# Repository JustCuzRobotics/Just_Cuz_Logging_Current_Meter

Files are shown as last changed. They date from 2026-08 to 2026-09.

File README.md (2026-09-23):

# RC Logging Current Meter

A 150 A / 60 V inline power meter and datalogger for RC ESC test benches, a WM150-class
meter with live logging, a graphing touchscreen, and thermistor plus ESC-signal channels.

**Status: Rev A built, assembled and brought up (2026-08-25).** Display, capacitive touch,
all four analog channels, backlight and the ESC output all work. Voltage and thermistor are
calibrated. **Two known Rev A faults: the buttons are dead (footprint pad mapping) and
`JP1` ships open.** See "Known open items". Bring-up firmware is in `firmware/`.

Placement

---

## What it does

| Parameter | Value |
|---|---|
| Max voltage | 60 V DC (14S LiPo) |
| Max current | **150 A burst**, ~60 A continuous, limited by the XT60 rather than the sensor |
| Current sensor | ACS770KCB-150U, Hall, galvanically isolated, 100 µΩ conductor |
| MCU | Waveshare RP2040-Zero |
| Display | 3.5" 480×320 IPS, ST7796U + FT6336U touch + microSD, 14-way FPC |
| Logging | microSD **and** USB CDC CSV, up to 76 Hz (every sample tick) |
| Channels | current, pack voltage, 5 V rail, 1× 100 k NTC, plus ESC signal out |
| Board | 95 × 62 mm, 4 layer, 1 oz outer / 0.5 oz inner |
| Assembled PCB | ≈ $15/board delivered, at qty 10 (JLCPCB: bare board + SMT parts + assembly + shipping) |
| Complete unit | ≈ $44/board, adding the display, RP2040-Zero, connectors, NTC and hardware |

**Read the accuracy budget in [`DESIGN.md`](DESIGN.md) §5 before trusting a number.** Short
version: honest between roughly 30 A and 150 A, and increasingly meaningless below ~20 A,
because a ±1%-of-full-scale nonlinearity term is a fixed ±1.5 A regardless of reading. That
is inherent to putting a 150 A Hall sensor on a small current. For *comparative* testing,
same board, same session, ESC A vs ESC B, the systematic terms cancel and repeatability is
far better than the absolute figures.

## Two ideas worth sharing

**The ratiometric trick (§4.2).** The sensor's output scales with its own supply, which here
is raw USB VBUS, sagging with cable resistance and modulated by the display backlight PWM.
Rather than fight that with a regulator, a second divider measures the 5 V rail, and the
current is recovered from the *ratio*. Both V_CC and V_REF cancel algebraically, so accuracy
depends only on two resistor ratios and the sensor's own spec.

**The current path crosses the short dimension.** The ACS770's terminals sit side by side,
so rotating it 90° and stacking the connectors above and below gives a ~28 mm connector-to-
connector path. The ground return, not the sensor, turns out to dominate the loss budget.
See §8.

---

## Repository layout

```
Logging_Current_Meter.kicad_sch    schematic
Logging_Current_Meter.kicad_pcb    board, 95 × 62 mm, 4 layer
LCM.kicad_sym / LCM.pretty         all project symbols and footprints, self-contained
production/                        gerbers, BOM, positions and IPC netlist as sent to fab
DESIGN.md                          the real documentation, reasoning, maths, decisions
BOM.md / BOM.csv                   bill of materials, generated from the schematic
generator/                         the Python that builds and checks all of the above
firmware/                          bring-up diagnostic and the touchscreen UI, one folder per sketch
tools/capture_stream.py            records the meter's USB CSV stream on a PC
tools/log_analyzer.py              GUI: graphs, summary CSV and run comparisons from SD logs
libraries/JCR_TouchScreen/         reusable ST7796 + FT6336U display and touch library
COMMIT_TIMELINE.md                 full detail behind every commit, newest first
```

`DESIGN.md` is the substantive document; this README is only an index. It records *why*
each choice was made, including the ones that turned out wrong and were reversed.

---

## The generator / verifier toolchain

The schematic and board are hand-edited in KiCad, but every mechanical change is applied by
script and checked by an independent verifier. The rule throughout: **the checker re-reads
the finished file from disk and re-derives everything, so it can disagree with the tool that
wrote it.**

**Requires KiCad 10 or newer.** The schematic and board are now in KiCad 10 format
(`20260306` and `20260206`), written by KiCad itself. KiCad refuses to open files stamped
newer than the running version, so an older install will not open this project at all.

```bash
cd generator

# check, read-only, safe at any time
python3 verify.py     ../Logging_Current_Meter.kicad_sch ../LCM.kicad_sym
python3 verify_pcb.py ../Logging_Current_Meter.kicad_pcb ../Logging_Current_Meter.kicad_sch

# regenerate derived artefacts
python3 gen_bom.py                                    # BOM.md + BOM.csv from the schematic
python3 copper_budget.py ../Logging_Current_Meter.kicad_pcb   # 150 A loss budget
python3 region_map.py    ../Logging_Current_Meter.kicad_pcb   # the §14 layout map
python3 render_pcb.py    ../Logging_Current_Meter.kicad_pcb ../placement.svg
```

> **`gen_sch.py` is a historical build script, not a live tool.** `generator/kicad8.py`
> hardcodes `SCH_VERSION = 20231120`, so re-running it would overwrite the KiCad 10
> schematic with a KiCad 8 one and discard every edit made in KiCad since. `gen_pcb.py`
> was updated for KiCad 10; `gen_sch.py` was not.

`verify.py` rebuilds the netlist **geometrically**, so pins, wire endpoints and label anchors
sharing a coordinate are one node, then compares it against an independently written
expectation of all nets and pin connections. `verify_pcb.py` runs nine checks over the
board: s-expression syntax, footprint inventory against the schematic, net coverage, board
extent, courtyard overlaps, stale net names, pour and stitching integrity, components inside
soldermask openings, and pad-to-pad clearance against the resolved netclass rules.

Both currently pass clean.

> **`gen_pcb.py` will refuse to run its `place` or `pour` stages once the board has routed
> tracks**, because both would destroy hand routing. Override with `--force` only after
> re-syncing the placement table from the board.

Every check in `verify_pcb.py` exists because something actually went wrong: a quoted
s-expression tag that made KiCad reject the file, a net rename that left a dead name on a
live pad, a resistor placed inside a soldermask aperture, a netclass clearance that made a
0.5 mm-pitch connector unroutable. The commentary in the source explains each one.

---

## Known open items

### Rev A hardware faults

- **`JP1` ships open — bridge it or the display is dead.** It is the display's only supply.
  Bridge pad 2 (`DISP_VCC`) to pad 1 (`+5V`). No backlight, no SPI and no I²C until you do,
  which makes it look like a much bigger problem than it is. `DESIGN.md` §9.
- **`J7` needs a TYPE A (same-side) FFC cable.** The one in the display's box is Type B and
  reverses the pin order, putting 5 V on the module's `SD_CS` while `VCC` sits unpowered.
  14 pin, 0.5 mm pitch, Type A, ≤100 mm. `DESIGN.md` §9.
- **SW1/SW2 are dead — footprint pad mapping is wrong.** `SW_TS-1187A` was remapped
  assuming internal pairs 1–3/2–4; they are 1–2/3–4, so both buttons short `BTN1` to `GND`
  permanently. Rev B fix, plus a lift-two-legs bodge for Rev A. Calibration runs from
  serial commands instead. `DESIGN.md` §9.
- **RV1 footprint.** Corrected in the library to the real 3362P triangle but **not yet
  applied to the board**. *Update Footprints from Library* moves all three pads 1.27 mm and
  needs `T_NODE` and `T_POT_TOP` re-routed. `DESIGN.md` §4.4.
- **D1 / U1 courtyards overlap by 3.49 × 0.45 mm.** Courtyard margin only — no pad, body or
  silk inside it. KiCad will keep flagging it. Not a bug.

### Firmware

- **Bring-up diagnostic is complete** and lives in `firmware/display_bringup/`. It exercises
  all 20 GPIO, reports pass/fail per subsystem with net names, and runs the calibration
  routines.
- **Current gain is the last uncalibrated channel.** Voltage, thermistor and the current
  zero are done and baked in.
- **The touchscreen UI is built and running**, in `firmware/logging_current_meter_FABLE/`
  (v3.6): live V/I/T/W, energy accumulation, an autoscaled 5 s graph, **Test Mode** (ESC
  signal on GP1 for uni- or bidirectional ESCs — manual buttons or slider with a dead-man
  option, ramped auto-cycle, and a counted **Log Test** that records itself), **SD logging**
  (manual, Test-cycle or current-threshold start, 1–15 min duration) with a **USB CSV
  stream**, a Settings screen
  with flash persistence and a settable wall clock that stamps every log with the date and
  time it was recorded, dark and navy themes, a tunable weighted filter on the V and I
  readings, and a touch diagnostic screen with a serial telemetry harness. Its display and
  touch stack is factored out into `libraries/JCR_TouchScreen/`. Architecture and the
  measured sampling constraints are in `DESIGN.md` §11.
- **Touch responsiveness fading with use is under investigation.** v3.1b's register
  watchdog found the FT6336U's mode register losing its value on its own (47 times in
  39 minutes) and now rewrites it within 500 ms; the per-register breakdown in v3.1c will
  say whether the part is resetting or one register is flaky.
- **v3.2a is bench-verified** (ESC timing, SD logging, USB stream, log analyzer).
  **v3.3** (the Test Mode rework), **v3.4** (the wall clock), **v3.5** (ESC arming, pre-roll
  and stop escalation) and **v3.6** (cycle mode: STOP→SPIN / SPIN→SPIN in place of the old
  mirrored DIRECTION) are compile-checked and host-tested; each bench run has fed the next,
  and v3.6 is not yet on the bench.
- ~~**microSD MISO tri-state risk.**~~ Inconclusive so far, and **not a blocker** — the
  panel is driven write-only and works. With no card in the slot nothing drives MISO on
  these modules, so `0xFF` is the expected reading. The §11 question only has meaning with
  a card inserted.

## Sourcing note

Three cost figures get confused, so to be explicit. `BOM.md`'s **$10.75** is the theoretical
SMT parts cost at LCSC unit prices, and it is the only one the generator computes. The
**$15** above is what a delivered assembled board actually cost at qty 10, and the real
PCBA line came in at $11.06/board against that $10.75 estimate, which is close enough to
validate the generated BOM. **$44** is a complete working meter, and the display alone is
$18.99 of it. All three are at qty 10; setup and shipping amortise, so a one-off build costs
considerably more per board.

The ACS770 is marked *not for new designs* but remains in stock. **ACS772KCB-150U-PFF-T is
a drop-in replacement requiring no board changes at all**, same package, same 26.66 mV/A,
same quiescent output, same ratiometric behaviour, same load limits. `DESIGN.md` §4.1.1 has
the full comparison, including which of the commonly-quoted differences are wrong.

## Licence

- **Hardware** (schematic, PCB, footprints, symbols, BOM, documentation):
  [CC BY-NC-SA 4.0](LICENSE), plus the additional permissions below.
- **Software** (the Python in `generator/`):
  [PolyForm Noncommercial 1.0.0](generator/LICENSE), plus the same additional permissions.

### What you can do

Build one. Build several. Modify the design. Use it at work, in a business, in a makerspace,
in a classroom, or in a paid repair shop. Put it in a monetised YouTube video, a paid course,
or a magazine article. Publish your modified version, as long as you credit this project and
licence your version the same way.

### What you cannot do

Sell the design files. Sell hardware built from them, whether assembled boards, bare PCBs, or
kits. Bundle either into a product you sell. Selling kits is how this project funds itself,
so that part is reserved.

Want to sell something based on this? Ask. Contact **team@justcuzrobotics.com**.

### Why it is written this way

CC BY-NC-SA's "NonCommercial" clause is broader than the intent above; read strictly it would
also block using one at work or in a monetised video. The additional permissions in the
LICENSE files grant those uses explicitly, so the only real restriction is on selling the
design or hardware.

Because commercial sale is restricted, this is source-available rather than open source in
the OSI or OSHWA sense.

Copyright © 2026 Seth Schaffer / Just 'Cuz Robotics

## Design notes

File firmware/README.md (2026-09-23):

# Firmware

| Sketch | Purpose |
|---|---|
| `display_bringup/` | Full board diagnostic and calibration tool. Exercises all 20 usable GPIO, reports pass/fail per subsystem with net names, and fits the analog calibration constants |
| `logging_current_meter_FABLE/` | **The current UI (v3.6).** Live V/I/T/W, energy and run timer, autoscaled 5 s graph, Test Mode (manual / ramped cycle / logged cycle test, one-direction or bidirectional ESCs), **SD logging with manual / cycle / current-threshold start and a USB CSV stream**, Settings with flash persistence, a settable wall clock that stamps logs, two themes, tunable V/I filter, touch diagnostics with a serial telemetry harness. One module per concern; built on `libraries/JCR_TouchScreen/` |
| `FABLE_DEV_TEST_SCREEN/` | Minimal touch-reliability test firmware. The quickest way to prove a panel and its touch mapping in isolation |
| `logging_current_meter_ui/` | Superseded predecessor (v1.7, Arduino_GFX). Kept as a reference until the new UI is bench-verified |
| `touch_dev_test/` | Earlier touch experiment. Superseded; not a reference |
| `_archive/` | Point-in-time copies of superseded firmware, kept as rollbacks. Not compiled — the extensions are deliberately not `.ino` |

**Datalogging to microSD and the USB stream are built as of v3.2** (compile-checked and
simulated on the host; not yet bench-verified). See *Logging* under
`logging_current_meter_FABLE` below. `tools/capture_stream.py` records the stream on a PC.

---

## `display_bringup`

**Everything reports over USB serial at 115200.** The display is treated as one more
subsystem under test — if the panel is dead, every other test still runs and still reports.
Do not rely on the screen to tell you anything.

> **USB power only.** Nothing in the 60 V current path, except during a deliberate voltage
> calibration. The sketch checks `V_PACK` at boot and shouts if it sees pack voltage.

### Toolchain

- **Board:** Arduino IDE → *"Raspberry Pi Pico/RP2040"* by **Earle Philhower**, board
  **Waveshare RP2040 Zero**
- **Library:** **"GFX Library for Arduino"** by *moononournation*. **Not Adafruit_GFX** —
  different library, different header, no ST7796 driver. Required by `display_bringup`
  and by the superseded `logging_current_meter_ui` only
- **Touch:** no library; the FT6336U is driven register-direct
- **Serial Monitor:** 115200, and **set the line ending to Newline** or no command you type
  will ever register

### Commands

| | |
|---|---|
| `a` / `A` | analog report, with expected values / streaming at 2 Hz |
| `b` | button report — idle level, press count, hold time, measured bounce |
| `c` | show the stored calibration constants |
| `s` | GPIO bridge / short test (unplug the ribbon first) |
| `k` | backlight ramp |
| `m` | MISO read-back, the `DESIGN.md` §11 test |
| `d` | display test pattern |
| `t` / `x` | touch controller scan and identity / coordinate stream |
| `g` | **live V/I graph — 5 s scrolling window, volts blue, amps red** |
| `e` / `l` | ESC signal output on GP1 / GP0↔ESC_SIG loopback |
| `n` / `v` / `i` | thermistor / voltage / current calibration |
| `r` / `?` | re-run the full sequence / help |

Streams stop on any key — an actual character, not a bare Enter.

### Calibration

Constants are **baked into the top of the sketch** and applied from boot, so they survive a
reflash. Each routine prints `#define` lines to paste back in. Press `c` to see what is
stored and which channels are genuinely calibrated.

Current state: voltage **fitted**, thermistor **fitted**, current **zero fitted / gain
nominal**. Full procedure and the reasoning behind each choice is in `DESIGN.md` §6.

Three things that will waste your time if you skip them:

- **Voltage needs two points with an offset**, not one through the origin. There is a real
  8.2 ADC count zero offset; ignoring it costs over 1 % at low pack voltages.
- **Fit the current gain at the highest current you can source.** The ±1.5 A nonlinearity
  floor is ±5 % of a 30 A fit but ±37 % of a 4 A one.
- **Do not use an ice bath for the thermistor.** Wet leads shunt it by ~340 kΩ — a 49 %
  error at 0 °C and 2 % at 100 °C. Room temperature plus boiling gives 77 °C of spread and
  works properly.

### Before first power-up on a new board

Board unpowered, DMM in continuity mode. All three of these cost an evening each the first
time. `DESIGN.md` §9 has the detail.

1. **Bridge `JP1`** — pad 2 (`DISP_VCC`) to pad 1 (`+5V`). It ships open and it is the
   display's only supply. Confirm pad 2 is *not* also bridged to pad 3.
2. **Use a Type A (same-side) FFC cable** for `J7`. The one in the display's box is Type B
   and reverses the pin order.
3. **Check `R11`–`R14` are fitted.** All four are 0 Ω placeholders in the SPI and backlight
   paths; a missing one is an open circuit, not a default.

### Known Rev A fault

**SW1 and SW2 are permanently shorted to GND** — the `SW_TS-1187A` footprint pad remap
assumed the wrong internal pairing. Everything is therefore driven by serial commands. Any
firmware built on this must not assume the buttons exist. `DESIGN.md` §9.

### Pin map

Mirrors `EXPECTED_MCU` in `generator/verify.py`. Verified against both that and the
module's own pin table.

| FPC | Module | Net | RP2040 |
|---|---|---|---|
| 1 | VCC | `DISP_VCC` | via `JP1` |
| 2 | GND | `GND` | — |
| 3 | LCD_CS | `LCD_CS` | GP5 |
| 4 | LCD_RST | `LCD_RST` | GP7 |
| 5 | LCD_RS | `LCD_RS` | GP6 |
| 6 | SDI (MOSI) | `SPI_MOSI` | GP3 via `R12` |
| 7 | SCK | `SPI_SCK` | GP2 via `R11` |
| 8 | LED | `DISP_LED` | GP8 via `R14` |
| 9 | SDO (MISO) | `SPI_MISO` | GP4 via `R13` |
| 10 | CTP_SCL | `CTP_SCL` | GP11 |
| 11 | CTP_RST | `CTP_RST` | GP12 |
| 12 | CTP_SDA | `CTP_SDA` | GP10 |
| 13 | CTP_INT | `CTP_INT` | GP13 |
| 14 | SD_CS | `SD_CS` | GP9 |

Analog: GP26 `I_SENSE`, GP27 `V_PACK`, GP28 `T_SENSE`, GP29 `V5_SENSE`.
Other: GP0 spare (J13 pad), GP1 `ESC_SIG_MCU`, GP14/GP15 buttons.

---

## `logging_current_meter_FABLE`

The working UI. **Uses no third-party graphics library** — the display, touch and text
stack lives in `libraries/JCR_TouchScreen/`, which must be on the Arduino library path
before this sketch will build:

```
arduino-cli compile --fqbn rp2040:rp2040:waveshare_rp2040_zero firmware/logging_current_meter_FABLE
```

Rather than copying the library into the sketchbook and forgetting to re-copy it, make the
sketchbook entry a junction to the repo copy — then every library edit is what the IDE
compiles:

```powershell
New-Item -ItemType Junction -Path "$HOME\Documents\Arduino\libraries\JCR_TouchScreen" `
         -Target "<repo>\libraries\JCR_TouchScreen"
```

**The panel is IPS and needs display inversion on.** `Config.h` sets `LCD_IPS 1`, which the
library turns into `INVON`. Without it every colour displays as its complement — black is
white — which is exactly how v2.0 through v3.1a looked, and why the themes made no sense
until v3.1b.

### Why touch is arranged the way it is

These panels are notorious for dropped taps, and the cause is not the hardware. The
FT6336U ships in trigger mode, where `CTP_INT` only pulses on state *changes*, so a short
tap can be missed outright; and reading touch from the drawing loop means any slow frame
stretches the gap between reads until brief contacts land and lift unseen. A third trap:
monitor mode is enabled by default and quietly drops the scan rate after ~30 s idle, which
reads as "touch goes dead if you leave it alone".

So the arrangement is inverted. **Core 1 owns touch and the ADC; core 0 owns the display.**
The controller runs in polling mode and is sampled at a fixed 200 Hz, interleaved *between*
the four ADC channel bursts so a ~5 ms acquisition can never delay a touch sample by more
than one channel. Press and release become queued events, so a slow frame delays the
*reaction* to a tap, never its *registration*.

Four rules keep that true as features are added. They are restated in the sketch header:

1. Core 1 never blocks, prints or draws — sampling and touch servicing only.
2. Core 0 may be arbitrarily slow; drain touch events every pass regardless.
3. Never repaint the whole screen per tick. Chrome once on entry, then only the fields
   that changed. A full-screen fill is ~60 ms even at 40 MHz.
4. Core 0 never touches the ADC; core 1 never touches SPI.

### Layout

One file per concern. `Config.h` holds the pin map, bus rates and **the calibration
constants** — that is the file to edit after running `display_bringup`'s `v`/`i`/`n`
routines (Settings → DUMP prints the current ones over serial). `Layout.h` holds every
pixel coordinate and touch target, so retargeting to another panel size is one file.
`Sampler.*` is the core-1 ADC, the V/I weighted-moving-average filter and the graph ring;
`Settings.*` the user settings and their EEPROM persistence (explicit Save only — a flash
write halts both cores for a few ms); `Clock.*` the wall clock and its date maths
(unit-tested on the host), `ScreenClock.cpp` the SET CLOCK screen; `EscOut.*` the ESC output and motion engine on GP1 (the
core's Servo library — PIO, `writeMicroseconds()`, fixed 50 Hz — OFF at boot, always arms at
idle with a 2 s hold; manual, ramped cycle and Log Test phases), `EscProfile.h` the pure
profile maths (unit-tested on the host), `ScreenTest*.cpp` the three Test Mode tabs; `Logger.*` the SD
log, its triggers and the USB stream; `Version.h` the version string the banner and log
headers share; `Theme.*` the
two palettes behind the `COL_*` macros; `Widgets.*` the button chrome and cached fields;
`Screens.*` navigation, with one `Screen*.cpp` per screen.

### Serial keys (115200)

| key | does |
|---|---|
| `d` | once-per-second `[tp]` telemetry line: touch rate, UI rate, worst frame, tap latency, every touch counter, controller register drift per register, core-1 tick health |
| `r` | reset the touch counters |
| `t` | re-initialise the touch controller from core 1 |
| `L` | synthetic ~60 ms core-0 load per loop |
| `f` | filter 0 ↔ 20 samples |
| `e` | ESC output arm (idle 1000 µs, 2 s hold) / cut, then prints the ESC state |
| `p` | print the ESC state — attached, set point, pulse on the pin, hold/cycle |
| `s` | USB CSV stream on/off (not saved — the LOG screen's SAVE persists it) |
| `g` | SD log start / stop |
| `m` | remount the SD card (runs the read-back test) |
| `c` | the wall clock. `c` alone prints it; `c 1790084323` sets it from epoch seconds; `c 2026-09-23 14:05:30` sets it from a typed date. This is the only key that takes an argument, so it reads to the end of the line (or a 2 s gap between characters) |

**Every serial line that is not a CSV data row starts with `#`** as of v3.2, so a capture
can separate data from the banner, `[tp]` telemetry and `[log]` events by the first
character.

The `[tp]` line is the touch-investigation tool: `TP` dropping means core 1 is starved,
`lat` climbing with `TP` steady means core 0 is slow, `dn` not counting on a real tap means
the controller stopped reporting, and `drift=[a/b/c/d]` counts the controller's four
configuration registers found not holding their values (rewritten automatically).

### ESC output — the v3.1 timing bug

v3.1 drove GP1 with `analogWriteFreq(1e6/period)` + `analogWriteRange(period)`. **arduino-pico
clamps `analogWriteFreq()` to ≥ 100 Hz, silently**, so the 50 Hz frame ran at 100 Hz on a
20000-count range and every pulse was half width: "1000 µs idle" was 500 µs, "2000 µs"
was 1000 µs (any frame longer than 10 ms was scaled by 10000/period). Some ESCs reject a
500 µs pulse and never arm; others accept it as zero throttle. v3.2 uses arduino-pico's
bundled **Servo** library instead (PIO state machine, `writeMicroseconds()`), which is what
this should have used from the start. Its frame is fixed at 20 ms (50 Hz, a compile-time
constant in the library), so Test Mode's frame-period stepper is gone. It is attached as
`attach(pin, 1000, 2000, 1000)`: plain `attach(pin)` starts at 1500 µs. Check the waveform
on a scope before trusting a test — expect a 20 ms frame and a 1000 µs pulse after arming.

Arming now always emits 1000 µs for 2 s before the set point or a cycle applies, and the
set point resets to idle on arm. ESCs refuse to arm when their first frames carry
throttle.

### Test Mode (v3.3, arming reworked in v3.5)

Three tabs under one header: **MANUAL | CYCLE | LOG TEST**, with the arm/stop button at top
right. Leaving Test Mode does not stop a running cycle — the amber strip says the output is
live.

**The arm/stop button escalates** (v3.5), because "stop the motor" and "make the pin dead"
are different needs and an ESC charges several seconds of start-up for the second one:

| face | tap does | when |
|---|---|---|
| **ARM** | signal up at idle, 2 s hold | output off |
| **STOP** | idle now, signal still up — the motor stops, the ESC stays armed | something is moving |
| **CUT** | output off (at most one more idle pulse, within a 20 ms frame) | already at idle, nothing running |

Holding the button for a second cuts from a press that started on STOP. A press that started
on ARM never repeats, and sliding a finger off the button cancels the hold.

Whenever the output sits live at idle with nothing running, a fuse cuts it on its own: 30 s
after a run ended by itself, 5 minutes after a stop you asked for. Touching the throttle or
starting anything cancels it, and the MANUAL status line counts the 30 s one down.

**Pre-roll** (v3.5): every run — cycle or Log Test — starts with the output at idle for
**ESC PRE-ROLL** (Settings, 0–15 s, default 5 s) before the first ramp, with the 2 s arming
hold inside it. An ESC ignores throttle until it has finished its start-up beeps, so without
this the first ramp is half eaten and the motor jerks. Set it longer for an ESC with start-up
music. START also works with the output already live: it commands idle and pre-rolls, rather
than making you stop first.

- **ESC type** (MANUAL tab, locked while armed; an arrow icon, one head or two):
  **ONE DIRECTION** arms and idles at 1000 µs; **BIDIRECTIONAL** arms at 1500 µs neutral,
  with reverse below. Every arm holds idle for 2 s first. (Logs and serial still write the
  short tokens `esc=UNI` / `esc=BIDI`.)
- **Small/big step pairs:** wherever a row has a fine and a coarse button (MANUAL ±10/±50,
  the CYCLE editor), the coarse one is drawn in lime with a double ring.
- **MANUAL:** BUTTONS (−50 −10 +10 +50) or SLIDER (tap anywhere to jump, drag to adjust;
  BIDI centres on 1500 with a small detent). RELEASE: **HOLD** keeps the value when you lift;
  **DEAD-MAN** drops to idle on lift — and also if the UP event is lost or touch samples stop
  for 60 ms. Switching into slider + dead-man drops the set point to idle. IDLE returns to
  idle/neutral while staying armed.
- **CYCLE / LOG TEST** share one saved profile, edited by tapping a tile and using the
  editor row (hold 1 s to repeat at 5/s):

| Tile | Range | Steps |
|---|---|---|
| LOW US (SPIN→SPIN only; in STOP→SPIN it is the type's stop pulse, greyed) | 1000 – 2000 | 10 / 50 |
| SPIN US / HIGH US | 1000 – 2000 | 10 / 50 |
| RAMP UP / RAMP DOWN ms | 0 – 3000 (0 = instant step) | 50 / 500 |
| DWELL HI / DWELL LO ms | 500 – 180000 (3 min) | 50 / 500 below 5 s, **1 s / 10 s above** |
| CYCLE MODE | STOP→SPIN · SPIN→SPIN | ◀ ▶ |
| CYCLES (LOG TEST only) | 1 – 999 | 1 / 10 |

  **CYCLE MODE** (v3.6) decides what the bottom of a cycle is. **STOP→SPIN** locks the low end
  to the ESC type's stop pulse (1000 one-direction, 1500 bidirectional) and leaves SPIN US free
  across the whole 1000–2000 band — so a bidirectional ESC runs *backwards* simply by setting
  SPIN below 1500. The number on the screen is the number on the pin: no mirroring, and no
  direction setting (the v3.3–v3.5 DIRECTION tile is gone). **SPIN→SPIN** frees both ends, for
  cycling between two running points — two throttle levels, or one side of neutral to the other.
  Either order is allowed, so a profile can ramp downward. Note that a pulse below 1500 only
  means reverse if the ESC's own firmware is in bidirectional (3D) mode; otherwise it is just a
  low forward throttle. In SPIN→SPIN the run eases from the pre-roll's idle into LOW over the
  ramp-up time (a LEAD-IN phase) rather than stepping; STOP→SPIN skips it, since its low end is
  idle already. Changing ESC TYPE resets the cycle's low end to the new type's stop pulse and
  the mode to STOP→SPIN, because 1000 µs means "stopped" under one type and "full reverse"
  under the other.

  Millisecond tiles change gear with their own value: a 3-minute dwell set 500 ms at a time
  would be 360 taps, so above 5 s the buttons become 1 s and 10 s and relabel themselves
  (`+1 S`, `+10 S`) as you cross the threshold. Dwells are stored as 32-bit values for this.

  Defaults (RESET DEFAULTS, tap twice within 2 s): STOP→SPIN, spin 1500 µs (1750 for a
  bidirectional ESC), ramps 1000 ms, dwells 3000 ms, 10 cycles. The profile is locked while a run is
  active and snapshotted at its start.
- **CYCLE** runs RAMP UP → DWELL HI → RAMP DOWN → DWELL LO until STOP CYCLE (which leaves
  the output armed at idle). LOG MODE = CYCLE still auto-logs these runs.
- **LOG TEST**: opens `LOG_<n>_TEST_<V>V.CSV`, the pre-roll at idle (arming hold inside it),
  N cycles, 5 s post-roll, closes the log (`reason=complete`) and stays live at idle with the
  30 s fuse running. Starting it with the output already live is fine — it goes to neutral
  first, which also means the card mount can never block with a motor under throttle. ABORT TEST jumps to the post-roll at idle; header STOP
  cuts the output and finishes the post-roll unpowered — either way the spin-down is logged
  and the file ends `reason=aborted`. The header carries a `# profile …` line (ESC type,
  pulses, ramps, dwells, cycles, cycle mode) that the log analyzer shows in its stats box,
  and the main chart gains an ESC-pulse strip. While a test runs, the LOG screen's
  START/STOP and serial `g` are refused, the DURATION limit does not apply, and the CURRENT
  trigger stays out of the way.

### Settings

Six rows: **THEME**, **FILTER**, **CLOCK** (below), **ESC PRE-ROLL** (0–15 s in 0.5 s steps,
hold to repeat), **SETTINGS** (SAVE — the only thing that writes flash, because a commit
halts both cores), and **TOOLS** (calibration DUMP over serial, and DEV MODE). Everything
takes effect in RAM immediately; SAVE is what survives a power cycle.

### The wall clock (v3.4)

There is no RTC chip and no backup cell, so the clock is an epoch base plus `millis()`. It
exists to stamp logs with the day and time they were recorded; it is not a timebase for
anything measured (that is still the 13.158 ms tick). Local time only — no timezone, no DST.

- **Setting it:** Settings → CLOCK → **SET CLOCK** (YEAR / MONTH / DAY / HOUR / MIN tiles and
  the same editor row as the cycle profile, hold to repeat; APPLY sets the seconds to 00), or
  the serial `c` command, which is accurate to the second. `tools\capture_stream.py` sends
  `c <epoch>` on connect, so plugging in the laptop syncs the meter (`--no-set-clock` to skip).
- **Across power cycles:** the time is copied into the settings blob at log start and stop,
  on an explicit SAVE, when the clock is set, and every 5 minutes while idle. On boot the
  clock resumes from that copy, so it comes back with the right date and the time of the last
  save — behind by however long the meter was off. That state is reported everywhere as
  **MAY BE BEHIND** (`state=restored` in a log header) rather than being passed off as exact.
- **Writes are deferred, never forced.** An EEPROM commit stalls both cores for a few ms, so
  no clock save happens while a log is recording or while the ESC output is live — a stall
  there would punch a hole in a capture, or leave the STOP button unanswered with a motor
  spinning. A save asked for at such a moment is remembered and written at the next idle pass.
- Drift between syncs is the crystal's, ±30 ppm worst case (about 2.6 s/day).
- Out-of-range times (before 2020 or after 2099) are refused, on the screen, over serial and
  on load from flash — milliseconds sent as seconds would otherwise stamp every log 2106.

### Logging (v3.2)

**LOG** tile on Home. All settings persist with **SAVE** (on the LOG screen; refused while
recording, because a flash commit pauses core 1). A red strip along the **bottom** edge of
every screen shows a log recording (solid) or CURRENT mode armed (dashed).

| Setting | Options |
|---|---|
| Mode (◀ ▶, wraps) | **MANUAL** (START/STOP or serial `g`) · **CYCLE** (Test Mode START CYCLE opens a log, STOP closes it) · **CURRENT** (starts when raw current > threshold for 3 ticks) |
| Rate | 76 / 38 / 15 / 7.6 / 1 Hz — decimations of the 13.158 ms tick (+ is faster) |
| Auto start above | 1–50 A, default **5 A** (CURRENT mode) |
| Duration | no limit, 1, 2, 3, 5, 10, 15 min — ends any log |

A stepper button that can go no further in its direction is greyed out.

- **Starting a log resets the energy counters and run timer**, so Live View and the file agree.
- CURRENT mode keeps **~0.5 s before the trigger** (negative `t_ms`), then re-arms only after
  the current has been below the threshold for 2 s — a run that outlasts its duration does
  not start a second file. With duration "no limit", a triggered log ends after 10 s below
  the threshold.
- An automatic start with no card mounted is **skipped, not mounted** — a failed mount
  blocks core 0 for ~2 s, which is not acceptable while a motor spins up. Insert the card and
  press REMOUNT SD (or serial `m`).
- Files are named `LOG_<n>_<MODE>_<V>V.CSV`, e.g. `LOG_07_CURRENT_22.4V.CSV`. `n` counts up
  from the highest number already on the card (the clock is not in the name — `n` is the
  order, and the date is in the header), `MODE` is the
  log-mode setting, and `V` is the pack voltage at the start — for a current trigger, the
  resting voltage just before the load came on, not the sag. Not pre-allocated (a power pull would otherwise leave
  megabytes of junk after the data); 512 B block writes, synced every 2 s. Mounting runs a
  write/read-back test, because the card shares MISO with the LCD (`DESIGN.md` §11).

**SD file** — `#` header lines (build, trigger, mode, rate, filter, ESC period, which
calibration constants are nominal), then:

```
t_ms,i_raw,i_filt,v_raw,v_filt,w,t_c,mah,wh,esc_us
```

`t_ms` from log start · `_raw` is the instrument, `_filt` is what the screen showed ·
`w` = `v_raw × i_raw` · `t_c` blank on a thermistor fault · `mah`/`wh` since log start ·
`esc_us` is what was on GP1 that tick, 0 = off. A `# clock` header line carries the wall
clock at the start (`2026-09-23 14:05:30 local  epoch=…  state=set|restored|unset`), and the
closing `# end` line carries the reason, rows, totals, peaks, drop counts and `stopped=`
(ISO, with a `T`, so every key on that line stays space-free). pandas: `pd.read_csv(f, comment="#")`.

**USB stream** — same rows **without energy**, `t_ms` since boot:

```
t_ms,i_raw,i_filt,v_raw,v_filt,w,t_c,esc_us
```

**Graphs:** `python tools\log_analyzer.py` (needs `pip install pandas numpy matplotlib seaborn`)
opens a picker for a log file or a folder of logs and saves charts, a summary CSV and run
comparisons to a `Log Graphs` folder beside them.

A line that does not fit the USB buffer is dropped and counted (`USB DROP` on the LOG
screen), never waited for. On a PC: `pip install pyserial`, then
`python tools\capture_stream.py` — it finds the port, turns the stream on if needed, and
writes `meter_<date>_<time>.csv` with a `pc_time` column.

Fonts are generated locally by `make_fonts.py` from a TTF — Russo One here, which is SIL
OFL, so the generator ships rather than the font.

---

Per `memory.md` §3: `git pull` at the start of a session, `git push` at the end.

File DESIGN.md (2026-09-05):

# ESC Test Bench Mainboard — Design Document

**Rev A — built, assembled and brought up. Display, touch, all four analog channels working.**
**Buttons dead (SW footprint fault, §9). Current gain not yet calibrated.**
150 A / 60 V inline power meter and datalogger. A WM150-class meter with live logging,
a graphing display, and thermistor + ESC-signal channels.

---

## 1. Specification

| Parameter | Value | Notes |
|---|---|---|
| Max voltage | 60 V DC | 14S LiPo. Divider sized for exactly 60 V → 2.86 V |
| Max current | 150 A **burst** | See §7 — XT60 and the PCB are both burst-rated, not continuous |
| Continuous current | ~60 A | Limited by the XT60 connector, not the sensor |
| Current sensor | ACS770KCB-150U-PFF-T | Hall, galvanically isolated, 100 µΩ conductor |
| Supply | USB-C only | RP2040-Zero ties VSYS directly to VBUS |
| MCU | Waveshare RP2040-Zero | 23 castellated pads, 20 usable GPIO — all allocated |
| Display | Hosyond 3.5" 480×320 IPS | ST7796U + FT6336U cap touch + microSD, 14-way |
| Logging | microSD **and** USB CDC | SD slot is on the display module — no extra hardware |
| Channels | current, pack voltage, 5 V rail, 1× 100k NTC | plus ESC signal out + telemetry in |

---

## 2. Architecture

```
 XT60/XT30 in ──┬── ACS770 (IP+ → IP-) ──┬── XT60/XT30 out
   (+)          │                        │
                │                        └─ R3/R4/R6 ─ R7 ── V_PACK → GP27
                │                           (divider)  (fault limiter + D1 clamp)
                │
   (-) ─────────┴──────── unbroken negative bus = GND = measurement reference

  ACS770 VIOUT ── R1/R2 ── I_SENSE  → GP26
  +5V (VBUS) ──── R5/R8 ── V5_SENSE → GP29     (ratiometric correction)
  +3V3 ── RV1 ── T_NODE ── NTC ── GND, tap → GP28

  RP2040-Zero ── SPI0 ──┬── ST7796U LCD
                        ├── FT6336U touch (I2C1, separate)
                        └── microSD          all on the display's 14-way connector
```

The current sensor sits in the **positive** leg only. The negative leg is an unbroken
copper pour, which is both the current return and the voltage reference for every
measurement. `V_PACK` is tapped at the **output** connector so it reads what the ESC
actually sees, including the drop across the sensor's conductor.

---

## 3. Pin map — all 20 usable GPIO

| Pin | Net | Function |
|---|---|---|
| GP26 / ADC0 | `I_SENSE` | Current, via 0.662 divider |
| GP27 / ADC1 | `V_PACK` | Pack voltage, via 21:1 divider |
| GP28 / ADC2 | `T_SENSE` | 100k NTC divider |
| GP29 / ADC3 | `V5_SENSE` | 5 V rail ÷2 — the ratiometric reference |
| GP0 | `GP0` | **spare** — brought out to the J13 pad |
| GP1 | `ESC_SIG_MCU` | ESC drive out (servo PWM or PIO DShot) |
| GP2 / GP3 / GP4 | `MCU_SCK/MOSI/MISO` | SPI0, shared LCD + SD |
| GP5 | `LCD_CS` | |
| GP6 | `LCD_RS` | data/command |
| GP7 | `LCD_RST` | |
| GP8 | `MCU_LED` | backlight, PWM |
| GP9 | `SD_CS` | microSD on the display module |
| GP10 / GP11 | `CTP_SDA/SCL` | I2C1, FT6336U touch |
| GP12 / GP13 | `CTP_RST/INT` | |
| GP14 / GP15 | `BTN1/BTN2` | MODE / ZERO-TARE |

**There is exactly one spare pin: GP0.** It was the ESC telemetry input until that
channel was dropped (see below), and it is brought out to `J13`, a plated 1.0 mm pad, so
the freed pin stays reachable rather than stranded on a castellation.

GP16 is the onboard WS2812; GP17–GP25 exist on the RP2040 die but are not brought out to
the 23 castellations. They *are* on bottom-side solder pads, but reaching them would
force the module to be reflowed rather than hand-soldered, with joints you cannot see or
rework — so Rev A does not.

### ESC telemetry removed

`J8` was a 1x04 carrying signal, telemetry, +5V and GND. AM32 ESCs present a standard
3-wire servo lead — **signal, +5V, GND, in that order** — and the telemetry channel was
never likely to be used, so J8 is now a `LCM:CONN_1x3`. `R18` (the 1k telemetry series
resistor) and `D2` (its BAT54S clamp) went with it, and the nets `ESC_TELEM` and
`ESC_TELEM_MCU` no longer exist.

> **Pin 2 is deliberately not connected.** The pad exists only so the servo plug seats
> squarely. The RP2040-Zero ties VSYS straight to VBUS, so wiring an ESC's BEC to +5V
> here would back-feed the USB host whenever both were plugged in. A `no_connect` marker
> sits on it in the schematic — which is also what stops KiCad's ERC reporting a floating
> pin — and `verify.py` fails if that marker is ever deleted, rather than simply
> whitelisting the pin.

The stock `PinHeader_1x03_P2.54mm_Vertical` lives in the KiCad installation and cannot be
synthesised by the generator, so the footprint in `LCM.pretty` was **derived from the real
1x04 already on the board** — KiCad's own pad geometry, one pin shorter, with the silk,
courtyard and fab outlines each pulled in by one 2.54 mm pitch.

---

## 4. Analog design and calculations

### 4.1 Current channel

ACS770KCB-150U, from the datasheet:
sensitivity **26.66 mV/A** (26.02–27.30), quiescent output **0.5 V** at 0 A,
**ratiometric to VCC** (VRAT = 100 %), load ≥ **4.7 kΩ**, load capacitance ≤ **10 nF**.

```
VIOUT = (VCC/5) × (0.5 + 0.02666·I)        →  VIOUT/VCC = 0.1 + 0.005332·I
At VCC = 5.000 V, I = 150 A:  VIOUT = 4.499 V
```

Divider **R1 = 2.4k, R2 = 4.7k**:

```
G1 = R2/(R1+R2) = 4.7/7.1 = 0.661972
ADC pin at 150 A = 4.499 × 0.661972 = 2.978 V    (10 % headroom under 3.3 V)
ADC pin at   0 A = 0.500 × 0.661972 = 0.331 V
Load on VIOUT    = 7.1 kΩ  ≥ 4.7 kΩ minimum      OK
Source current   = 4.5 V / 7.1 kΩ = 0.63 mA ≤ 3 mA max   OK
Source Z at pin  = 2.4k ∥ 4.7k = 1.59 kΩ
C4 = 10 nF       → −3 dB at 10.0 kHz
```

> **Why E24 and not E96.** These were 2k49/4k99 in the first draft. Neither exists as a
> JLCPCB *Basic* part — 2k49 0805 is Extended with 19 k in stock. 2.4k and 4.7k are Basic
> with millions in stock and no feeder fee. The ratio moves from 0.66711 to 0.661972,
> which costs nothing: it is a fixed gain that the calibration in §6 removes anyway.

**C3 = 10 nF sits directly on VIOUT and is the datasheet maximum.** Do not increase it.
The sensor's quoted noise figure (6 mV, ±3σ ≈ 0.225 A) is specified at exactly this value.

Resolution: 3.3 V / 4096 = 0.806 mV/LSB; 1 A = 17.65 mV at the pin → **0.046 A/LSB**.

### 4.1.1 Future option: ACS772KCB-150U is a drop-in

The ACS770 is marked *not for new designs* but remains in stock, and **Rev A is being built
with it.** If it ever goes short, the **ACS772KCB-150U-PFF-T** replaces it with **no board
changes of any kind** — no footprint change, no component values, no firmware constants.

Checked against both datasheets (`ACS770-Datasheet.pdf`, ACS772 datasheet), every parameter
this design leans on is identical:

| | ACS770KCB-150U | ACS772KCB-150U |
|---|---|---|
| Package | 5-pin CB, PFF leadform | 5-pin CB, PFF leadform |
| Sensitivity, typ | **26.66 mV/A** | **26.66 × V_CC/5 mV/A** |
| Quiescent out, unidirectional | 0.5 V | V_CC/10 = 0.5 V |
| Ratiometric | V_RAT = 100 % | yes — ±0.15 % QVO, ±0.3 % Sens |
| R_LOAD minimum | 4.7 kΩ | 4.7 kΩ |
| C_LOAD maximum | 10 nF | 10 nF |
| Primary conductor | 100 µΩ | 100 µΩ |

So §4.1's transfer function is unchanged, R1/R2 stay (150 A → 2.978 V), the §4.2
ratiometric cancellation still works so R5/R8/C6 stay, C3 is still exactly at C_LOAD(max),
and the 7.1 kΩ load still clears the 4.7 kΩ minimum. Only `U1`'s value string and the LCSC
line change — and the footprint name `LCM:ACS770_CB_PFF` becomes a misnomer, though the
geometry is right for both.

**What you gain:** total output error **±2.4 % → ±1.5 %** max, and sensitivity tolerance
±2.4 % → ±1 %. §5 notes gain calibration already removes the sensitivity term, so the real
benefit is the temperature-drift part of the budget.

**What you do not gain: the 200 kHz bandwidth is unusable in this design.** C4 = 10 nF on a
1.59 kΩ source puts the anti-alias corner at 10 kHz, and firmware decimates to ~2 kHz. The
sensor's 120 → 200 kHz never reaches the ADC. Exploiting it would mean shrinking C4, which
wrecks the anti-aliasing for a 2 kHz sample rate. Don't.

**Two cautions, neither requiring a change here:**

- **The supply zener is gone.** The ACS770 has one at 6.5–7.5 V / 30 mA; the ACS772 has
  none. Irrelevant on this board — V_CC arrives via `+5V → FB1 → +5VS` with no series
  resistor, so the zener was never acting as a clamp. Abs-max V_CC actually *improves*,
  6 V → 6.5 V. A 5.5 V TVS on `+5VS` would be insurance against a USB hot-plug transient;
  there is no footprint for one and Rev A does not add it.
- **VIOUT abs max drops 25 V → 6.5 V.** Nothing on this board back-drives VIOUT — `I_RAW`
  reaches only C3, R1 and the TP4 probe pad. The one genuinely dangerous probe slip, TP4 to
  TP1 (`PACK+`, 60 V), was already fatal at 25 V, so nothing changes.

> **Two figures widely quoted for this comparison are wrong.** Abs-max V_CC does **not**
> drop — it rises 6 → 6.5 V. And creepage/clearance goes **6.9 → 6.8 mm**, not 7.25 → 6.8;
> the ACS770 datasheet gives 6.9 mm for both D_CL and D_CR. Certified working voltage is
> 475 V_RMS reinforced on both.

> **Noise cannot be compared directly from the datasheets.** The ACS770 specs 6 mV at
> **10 nF** on VIOUT; the ACS772 specs 3.4 mV RMS at **1 nF**. This board runs 10 nF, which
> is off the ACS772's specified condition, so whether it lands better or worse than 6 mV
> there is not knowable from the datasheets — measure it if you swap.

### 4.1.2 Sensor supply and decoupling

Asked often enough to be worth answering here: **where is the ACS770's decoupling
capacitor?** It is `C1`, and it is not on the raw +5 V rail — the sensor gets its own
ferrite-isolated island.

```
+5V ──┬── C10 100 uF ── FB1 ──┬── +5VS ── U1.1  (VCC)
      │                 600R  ├── C1  100 nF
      │              @100 MHz ├── C2  10 uF
      └── (MCU, display)      └── R5 ── V5_SENSE divider
```

The `+5VS` net is exactly `{U1.1, FB1.2, C1.1, C2.1, R5.1}`.

| Part | Role | Distance from U1 pin 1 |
|---|---|---|
| `FB1` 600R@100MHz, 2A | series isolation from MCU/display switching noise | 3.52 mm |
| `C1` 100 nF | HF decoupling | **8.01 mm** |
| `C2` 10 uF | local bulk | 12.51 mm |
| `C10` 100 uF | +5 V bulk, upstream of FB1 | 9.62 mm |

**`C3` is not supply decoupling** and the two get confused. `C3` (10 nF) sits on `I_RAW`
/ VIOUT, 3.55 mm from U1 pin 3. It is the datasheet's *output* load capacitance, at the
specified **maximum** — the sensor's quoted 6 mV noise figure is characterised at exactly
this value. Do not increase it, and do not remove it thinking it is a bypass cap.

**Why R5 taps `+5VS` and not `+5V`.** This is the part that actually makes the
measurement work. Section 4.2 recovers current from `ADC_I / ADC_5V`, so the reference
divider must see the *same* rail the sensor runs on. It does — `R5.1` is on `+5VS`,
downstream of the ferrite. Any drop or noise across `FB1` is therefore common to both
the sensor output and the reference measurement, and cancels algebraically. Tapping R5
off `+5V` instead would leave the ferrite's drop uncancelled and would be a real bug.
It is worth checking this survives any future re-layout.

> **Known weakness: C1 is 8 mm from the pin, and the ordering is backwards.**
> Conventional practice puts a 100 nF decoupler under ~5 mm, and puts the shunt cap
> nearest the pin with the series element further out. Here the physical order along the
> rail is U1 → FB1 → C1 → C2, so the closest part to VCC is the series ferrite.
> Electrically the topology is correct (ferrite in series, caps shunting on the load
> side); only the placement fails to reflect it.
>
> It works regardless, for three reasons worth stating rather than assuming:
> the ACS770 is not a switching load (~14 mA steady, no fast transient demand); the
> bandwidth is deliberately discarded downstream (`C4` puts the anti-alias corner at
> 10 kHz against the sensor's 120 kHz, and firmware decimates to ~2 kHz), so HF supply
> behaviour never reaches the ADC; and the ratiometric architecture above cancels supply
> variation as common mode rather than relying on the rail being quiet.
>
> **Rev B: swap `C1` and `FB1`.** A series element's position along the run barely
> matters; a decoupling capacitor's does. That puts C1 about 2.5 mm from the pin at no
> cost.

### 4.2 The ratiometric trick (why R5/R8 exist)

The ACS770 output scales with its own supply, and that supply is raw USB VBUS — which
sags with cable resistance and, worse, is modulated by the display backlight PWM. Rather
than fight this with a regulator, measure it:

```
ADC_I  = VIOUT × G1 / VREF × 4095
ADC_5V = VCC   × G2 / VREF × 4095 ,   G2 = R8/(R5+R8) = 0.5

ADC_I / ADC_5V = (VIOUT/VCC) × (G1/G2) = (0.1 + 0.005332·I) × G1/G2

    I = [ (ADC_I / ADC_5V) × (G2/G1) − 0.1 ] / 0.005332          G2/G1 = 0.755319
```

**Both `VCC` and `VREF` cancel out of that expression.** Accuracy then depends only on
two resistor ratios and the sensor's own spec — not on the USB rail, not on the 3.3 V
LDO, and not on backlight ripple.

### 4.3 Pack voltage

**R3 = R4 = 100k, R6 = 10k**, split into two series parts so each stays inside its 150 V
working rating and the creepage doubles.

```
ratio = 10 / (100 + 100 + 10) = 10/210 = 0.047619      (exactly 21:1)
60.0 V → 2.857 V          resolution 16.9 mV/LSB
pack drain = 60 V / 210 kΩ = 286 µA continuous (17 mW) — negligible, but always on
source Z = 200k ∥ 10k = 9.52 kΩ  (+ R7 1k)
C5 = 100 nF → −3 dB at ~150 Hz, and it makes the source stiff enough for the SAR ADC
```

> Also moved off E96 for the same reason: 95k3 is Extended with 3.5 k in stock, 100k is
> Basic with 6.4 M. 21:1 is a rounder number to work with in firmware, and the extra
> headroom under 3.3 V is welcome.

### The five nets, and what R7 is actually for

`PACK+` and `V_PACK` are not the same net, and the divider does not tap `PACK+` at all:

| Net | Pads | V at 60 V in |
|---|---|---|
| `PACK+` | J1.1, J2.1, U1.4, TP1.1 | 60.00 |
| `LOAD+` | J3.1, J4.1, U1.5, **R3.1**, TP2.1 | 60.00 |
| `VPACK_MID` | R3.2, R4.1 | 31.43 |
| `VPACK_TAP` | R4.2, R6.1, R7.1, TP7.1 | 2.857 |
| `V_PACK` | R7.2, C5.1, **D1.3**, U2.6, TP8.1 | 2.857 |

`R3.1` sits on **LOAD+**, the sensor's output side — that is the §2 choice to read what the
ESC actually sees. `VPACK_TAP` and `V_PACK` are the same DC potential, because no current
flows into an ADC pin and so nothing drops across R7; they are separate nets only because
a component sits between them. **D1 therefore never sees 60 V** — pin 3 is on the 2.86 V
side, clamping the ADC pin to the rails.

> **Correction to rev A.** This paragraph used to read *"a cracked R6 puts the full pack
> voltage onto GP27 and destroys the RP2040"*. That is wrong. If R6 goes **open**,
> `VPACK_TAP` does rise toward 60 V, but through R3 + R4 = 200 kΩ — so the clamp draws
> (60 − 3.6) / 201 kΩ ≈ **280 µA**, which the RP2040's own input protection shrugs off.
> An open R6 is a benign failure that reads full scale, not a destructive one. R6 **short**
> is equally benign: the channel reads zero.

**What R7 is really for** is any fault that puts a *low-impedance* path from the 60 V bus
onto `VPACK_TAP` — both upper legs bridged, a 0 Ω or wrong-value part fitted at R3 or R4,
or a slipped probe lead. With 60 V driven straight onto the node, R7 holds the clamp
current to (60 − 3.6) / 1 kΩ ≈ **56 mA**, inside the BAT54S's 200 mA rating. Without R7
that fault is limited only by the diode's forward resistance, and it destroys D1 and the
GP27 pad with it. Note this is a live risk in layout as well as assembly: **R3 sits about
1 mm from the exposed LOAD+ pour**, so solder splash during bar assembly is a credible
route to exactly that fault.

D1 is a **BAT54S — the *series* variant**, pin 3 the common node. With GND on pin 1 and
+3V3 on pin 2 that gives a diode from GND up to `V_PACK` and another from `V_PACK` up to
+3V3, clamping excursions in both directions. The `A`/`C`/single variants of the BAT54
would *not* work here: swap in a BAT54C by mistake and the clamp does nothing.

**Both parts stay** — for a better reason than rev A gave.

This channel is **not** ratiometric — it is referenced to GND, so the 3.3 V LDO tolerance
(±2 % on a typical ME6211) is a direct gain error. **A one-point voltage calibration is
mandatory**; see §6.

### 4.4 Thermistor

```
+3V3 ── R10 (0R) ── RV1 (100k trim) ── T_NODE ── NTC 100k ── GND      tap → R9 → GP28
```

NTC on the bottom leg deliberately: one thermistor lead is at ground (quieter on a long
run to a motor), and both failure modes are unmistakable — an open lead reads 3.3 V, a
short to chassis reads 0 V.

```
V_node / 3V3 = R_ntc / (R_pot + R_ntc)          — ratiometric, VREF cancels exactly
25 °C, R_ntc = 100k, pot = 100k :  1.650 V
 0 °C, R_ntc = 336k             :  2.543 V
100 °C, R_ntc = 6.99k           :  0.216 V      (B = 3950)

Recover:  R_ntc = R_pot · x/(1−x),  x = ADC/4095
          T = 1 / ( 1/298.15 + ln(R_ntc/100k)/3950 )
```

Worst-case source impedance is 50 kΩ (when R_ntc = R_pot), far too high for the RP2040's
SAR input on its own — **C7 = 100 nF at the pin is what makes this work**, by supplying
the sampling charge locally.

RV1 is wired as a rheostat (wiper tied to pin 3). `R10` is a 0 Ω placeholder.

> **Correction to the 91k recommendation.** This used to say *"fit 91k there and RV1
> becomes a fine trim over 91–191 kΩ"*. That does not achieve what it claims. For the
> ~100 kΩ target, 91k puts you at **9 % of pot rotation** — the opposite end stop from
> where R10 = 0 leaves you (100 %). Neither is a fine trim.
>
> | R10 | Trim range | 100 kΩ sits at |
> |---|---|---|
> | 0 (as built) | 0–100 k | **100 %** — end stop |
> | 91k (old advice) | 91–191 k | **9 %** — other end stop |
> | **47k** | 47–147 k | **53 %** — centred |
>
> 47k also sits near the geometric mean of R_ntc across 0–100 °C (≈48 k), so it is
> defensible on resolution grounds too. Note that for motor temperatures specifically
> (25–100 °C, R_ntc 100 k → 7 k) the best-resolution R_pot is nearer **27 k**; the 100 kΩ
> target maximises sensitivity at *room* temperature, which is probably not what a test
> bench cares about. Decide the target before fitting anything.
>
> **As built and measured 2026-08-25: RV1 = 100.83 kΩ**, at the clockwise end stop. The
> pot value is roughly 20× less critical than the NTC's own R25 tolerance — 100.70 k vs
> 100.83 k moves the temperature by 0.03 °C.

> ### RV1 footprint — was the wrong 3362 variant, now corrected
>
> The part is **JIERR 3362P-1-104, LCSC `C48997913`** — 100 kΩ, 0.5 W, 7 × 6.8 mm,
> ~$0.19 @ 5.
>
> `LCM:Potentiometer_Bourns_3362P_Vertical` was originally built with **all three pads in
> a row** at (−2.54, 0), (0, 0), (+2.54, 0). That is the plain **`3362`**, not the
> **`3362P`**. The vendor EasyEDA model in `easyECADDownloader/` settles it:
>
> ```
> pad 1  (-2.54,  1.27)
> pad 2  ( 0.00, -1.27)     <- offset 2.54 mm perpendicular, centred
> pad 3  ( 2.54,  1.27)
> ```
>
> Pins 1 and 3 are **5.08 mm** apart with pin 2 offset **2.54 mm** — a triangle. As
> originally drawn, pin 2 had nowhere to go and the part would not have fitted.
>
> The two variants are easy to confuse because the 3362P's *side* view reads "2.5 + 2.5",
> which is the triangle projected flat and looks identical to the in-line 3362. **Only the
> top view distinguishes them.** The footprint is now rebuilt from the vendor pad data;
> 0.9 mm drill retained for hand insertion on a ⌀0.5 mm lead.
>
> **To apply:** the library name is unchanged, so KiCad's *Update Footprints from Library*
> fixes RV1 in place. Note **all three pads move 1.27 mm**, not just pin 2, so all 9 track
> endpoints on RV1 break — `T_NODE` and `T_POT_TOP` need re-routing. Verified against a
> copy of the routed board beforehand: 0 courtyard overlaps and 0 clearance violations at
> RV1's current position, so nothing else has to move.

---

## 5. Accuracy budget — read this before trusting a number

### Current

| Source | Contribution |
|---|---|
| Sensor sensitivity error | ±2.4 % **of reading** |
| Sensor nonlinearity | ±1 % **of full scale** = ±1.5 A |
| Sensor noise (10 nF on VIOUT) | ±0.225 A (±3σ) |
| Offset ±10 mV + magnetic remanence ≤400 mA | **removed by taring** |
| Divider ratio, 1 % resistors | ±1.1 % — **removed by gain calibration** |

Worst case after tare and gain calibration:

| Current | Absolute error | Relative |
|---|---|---|
| 150 A | ±5.3 A | 3.5 % |
| 50 A | ±2.9 A | 5.8 % |
| 10 A | ±1.9 A | **19 %** |

**The nonlinearity term is fixed at ±1.5 A regardless of reading**, so this instrument is
honest between roughly 30 A and 150 A and increasingly meaningless below ~20 A. That is
inherent to putting a 150 A hall sensor on a small current — not a flaw in this board. If
you need good 5–20 A resolution, that wants a second, smaller sensor or a shunt.

For *comparative* ESC testing — same board, same session, A vs B — the systematic terms
cancel and repeatability is far better than the absolute numbers above.

### Voltage
±2.2 % uncalibrated (dominated by the 3.3 V LDO), **~±0.3 % after a one-point
calibration**, thereafter limited by LDO tempco (~100 ppm/°C) and resistor drift.

### Temperature
Ratiometric, so no reference error. Realistically ±2 °C after trimming RV1, limited by
NTC tolerance and B-value spread.

### Measured on the first board, 2026-08-25

The predictions above held up. Recording the actuals, because they validate the model:

| Term | Predicted | Measured |
|---|---|---|
| Voltage gain error, uncalibrated | ±2.2 %, LDO-dominated | **−1.74 %** |
| Voltage after two-point calibration | ~±0.3 % | fit residual 0.000 V at both points |
| ACS770 quiescent vs nominal | part tolerance | **+5.40 %** (ratio 0.105399 vs 0.1) |
| Thermistor B | 3950 nominal | **3836.6** (−2.9 %) |
| Thermistor R25 | 100 k nominal | **97 988 Ω** (−2.0 %) |
| Zero-current reading after tare | ±2 A band | **−0.040 A** |

One term the budget above misses: the voltage channel has a real **8.2 ADC count zero
offset** (≈0.14 V), from ADC input leakage and D1's reverse leakage into the 10.5 kΩ node.
It only appears with the input floating — a connected pack swamps it — but it is why §6.1
now fits an offset as well as a gain.

> **Consider 0.1 % resistors for R1, R2, R5, R8.** They cost about five cents more and
> remove the ±1.1 % divider term before you calibrate anything.

---

## 6. Calibration procedure

**Rewritten 2026-08-25 after actually doing it on hardware.** The previous version was
written before anyone had a board and three of its four steps were wrong in practice.

All of it now runs from serial commands in `firmware/display_bringup/`, not from the
buttons — **SW1 and SW2 are dead on Rev A** (§9). Constants are printed to paste back into
the top of the sketch, and the current values are recorded there.

### 6.1 Voltage — `v`, TWO points, not one

> **Correction.** This used to say *"one point through the origin"*. That is wrong for
> this board. There is a real **8.2 ADC count zero offset** (≈ 0.14 V), so a fit through
> the origin reads **+1.12 % high at 10 V** and worse below it. Fit gain AND offset.

Feed the supply into the INPUT connector (J1/J2), low current limit, no load. Use two
widely spaced points and read the voltage from a meter, not the supply's display.

Measured on the first board: gain **−1.74 %** from nominal, which is the 3V3 LDO tolerance
landing on a GND-referenced channel exactly as §4.3 and §5 predict.

> **Live high voltage.** The bus copper is deliberately soldermask-free so bars can be
> soldered on. At 57 V that is a bare live conductor. §4.3 also warns that R3 sits ~1 mm
> from the LOAD+ pour — a slipped probe there puts 60 V on the ADC node.

### 6.2 Current — `i`, tare then gain

Model: `I = (ratio − quiescent) / sensitivity`, where `ratio = (ADC_I/ADC_5V)·(G2/G1)`.
Both VCC and VREF cancel (§4.2), so the two unknowns map onto the two steps.

1. **Tare at 0 A**, nothing in the current path. Measured quiescent on the first board is
   **0.105399**, +5.40 % from the nominal 0.1 — ordinary part tolerance. Re-tare each
   session: the ACS770 keeps up to 400 mA of magnetic offset after a large excursion.
2. **Gain at the highest current you can source.** This matters more than it looks. §5's
   nonlinearity is **±1.5 A of FULL SCALE, fixed at any reading**, so as a fraction of the
   calibration current it is the gain uncertainty you inherit:

   | Calibration current | Gain uncertainty |
   |---|---|
   | 4 A | ±37 % |
   | 10 A | ±15 % |
   | 30 A | ±5 % |
   | 150 A | ±1 % |

   Use a low current for a **check** point, never for the gain fit.

### 6.3 Thermistor — `n`, two points, and NOT an ice bath

> **Correction.** This used to say *"ice bath (0 °C)"*. **Do not.** Bare thermistor leads
> in water put a few hundred kΩ across the part — measured at roughly **340 kΩ**. That is
> a **49 % error at 0 °C and only 2 % at 100 °C**: a temperature-dependent error, which no
> two-parameter fit can absorb. Three ice-bath attempts produced B values of 2922, 3090
> and 3482 and R25 values of 57 k, 57 k and 87 k — all physically impossible for a part
> the DMM reads at 111 kΩ at 22 °C.

**Use room temperature and boiling instead.** 77 °C of spread settles B to 0.18 % against
0.13 % for a 0–99 °C pair. The cold point was never necessary.

Take each parameter from the measurement that gets it best:

- **B** from a wide span with **both ends verified** by a thermometer. Two independent
  runs gave 3834.9 and 3836.6.
- **R25** from one accurate absolute point: the thermistor **dry, in air**, against a good
  room reference. Every wet measurement is shunted. R25 moves ~4.5 % per °C of error in
  that reading, so read the reference meter — do not estimate it.

Fitted on the first board: **B = 3836.6, R25 = 97 988 Ω**.

If a genuine ice slurry ever happens — mostly crushed ice, minimal water, stirred, 30 s to
settle — this fit predicts **308 kΩ at 0 °C**. Use it as a *check*, never as a fit input.

### 6.4 Sanity check every fit

A fit returning a physically implausible part means the **data** is wrong, not the part.
The sketch now rejects B outside ±15 % and R25 outside ±25 % of nominal rather than
printing them as if they were usable.

---

## 7. The 150 A problem — quantified

This is the main thing to settle before layout.

**Connector.** XT60 is a 60 A continuous connector with roughly a 180 A burst rating.
150 A through it is fine for the seconds-long pulls typical of ESC testing and will
overheat on sustained load. The connector, not the board, is the limit. XT30 taps are for
small packs only (30 A).

**PCB copper.** IPC-2221 for external traces, 2 oz, 20 °C rise:

| Current | Required trace width (2 oz) |
|---|---|
| 60 A | ~27 mm |
| 150 A | ~97 mm |

Continuous 150 A through PCB copper is not practical at any sane board size. What *is*
practical is a short, wide, low-resistance bus that survives bursts on thermal mass:

```
25 mm long × 20 mm wide, 2 oz on both layers stitched (≈4 oz effective, t ≈ 0.14 mm):
  R = ρL/(Wt) = 1.68e-8 × 0.025 / (0.020 × 0.00014) ≈ 150 µΩ
  at 150 A → 3.4 W in the bus
  plus the ACS770's own 100 µΩ conductor → 2.25 W
  ≈ 5.6 W total during a burst
```

Five-plus watts is fine for a ten-second pull into a few grams of copper, and completely
unacceptable continuously. Mitigations for layout: keep the path as short as physically
possible, flood the bus with exposed (soldermask-free) copper so it can be built up with
solder or a copper braid, and stitch both layers with a dense via field.

---

## 8. PCB parameters — decided

| Parameter | Decision |
|---|---|
| Board size | **95 × 62 mm** — see "The 50 mm error" below |
| Layers | **4**, 1 oz outer / 0.5 oz inner (JLCPCB standard) |
| Connectors | XT60 and XT30 side by side, **one pair per 95 mm edge** |
| Current direction | **Across the 50 mm dimension**, top edge to bottom edge |
| ACS770 orientation | **Rotated 90°** so its terminals align with the current direction |
| Bus construction | Exposed copper (no soldermask) on L1 and L4, via-stitched, **10 AWG solid copper soldered along each** |
| Display | FPC only (J7). Module mounts to the **enclosure**, not the board |
| Expansion | Test point on every net, spare 3V3 / 5V / GND pads |
| Mounting | H1–H4, M3, unplated |

### Why the current crosses the short dimension

The ACS770's two current terminals sit **side by side, 10 mm apart** — not end to end.
The sensor is therefore only ~11 mm deep in the current direction, with its 20 mm body
projecting sideways where the signal pins are. Stacking the connectors top and bottom
with the rotated sensor between them gives:

### The 50 mm error

Rev A costed this budget with "XT60 footprint depth 9.1 mm". **That is the connector's
pad extent, not its body.** The F.Fab outline is 18.2 mm (XT60PW-M) and 17.2 mm
(XT60PW-F), and the vendor STEP models agree: the XT60PW occupies 15.5 × 18.2 mm of
board area, stands 8 mm tall, and mates horizontally. The body sits on the board.

The ACS770 was also costed at "10.8 mm deep in the current direction". Rotated 90° its
courtyard is **19.5 mm** in that direction — the 10 mm tab pitch plus two 9 mm-wide tab
slots and their stitching-via rings.

Corrected, with the real numbers:

```
board edge margin        1.5
J1 XT60-M body          18.2
bus gap                  2.0
U1 ACS770 courtyard     19.5
bus gap                  2.8
J3 XT60-F body          17.2
board edge margin        0.8
─────────────────────────────
minimum height          62.0 mm
current path            ~28 mm       J1 pad v=17.85 -> U1 tabs -> J3 pad v=45.65
```

The current path is unchanged at ~28 mm, which is the number that actually mattered —
only the dead space around it grew. **95 × 62 mm is still inside JLCPCB's ≤ 100 × 100 mm
bracket, so the change costs nothing but 12 mm of enclosure depth.**

### Copper budget at 150 A — as built

Measured from the finished board by `generator/copper_budget.py`, which reads the pad
geometry out of the `.kicad_pcb` rather than trusting a hand-written table. Segment
lengths are pad edge to pad edge. Copper is 1 oz outer on F.Cu + B.Cu plus the 0.5 oz
inner (In2 for the positive channels, the In1 plane for GND) = 0.0875 mm effective.

| Segment | Length | Bare PCB | + 10 AWG bar | P bare | P + bar |
|---|---|---|---|---|---|
| PACK+ J1.1 → U1 tab 4 | 2.29 mm | 44 µΩ | **6 µΩ** | 0.99 W | 0.14 W |
| ACS770 conductor | — | 100 µΩ | 100 µΩ | 2.25 W | 2.25 W |
| LOAD+ U1 tab 5 → J3.1 | 3.29 mm | 63 µΩ | **9 µΩ** | 1.42 W | 0.20 W |
| GND J1.2 → J3.2 | 24.58 mm | 315 µΩ | **63 µΩ** | 7.08 W | 1.41 W |
| **Total** | | | | **11.74 W** | **4.01 W** |

At 60 A continuous that is **0.64 W** with bars. The sensor remains the largest single
contributor, which is the right place for it — you cannot design that part away.

**The bus bars remain mandatory, but for a different reason than rev A supposed.**
Putting J1/J3 pin 1 directly on U1's terminal column left the positive segments only
2.3 mm and 3.3 mm of pour, so they are nearly free either way. **The whole problem is now
the ground return**, which has to run the full 24.6 mm past the sensor and carries 7.1 W
bare — 60 % of the total loss. That is the segment the bar has to cover.

Each soldermask opening therefore spans its segment's **entire** current path, pad edge to
pad edge. A bar only conducts where it is bonded; an opening shorter than the run leaves
the uncovered part at full PCB resistance.

### Layout consequences

The connectors need 33 mm of the 95 mm width for XT60 + XT30 side by side. The current
block therefore occupies roughly a 40 × 50 mm region, leaving about **55 × 50 mm for the
MCU, FPC connector, analog front end, buttons and test points** — roughly 56 % component
fill overall, which is comfortable on 4 layers.

Keep ≥ 2 mm between the exposed positive and negative bus channels. IPC-2221 only demands
~0.4 mm at 60 V, but exposed copper carrying molten solder during assembly deserves the
margin.

### Considered and rejected: Waveshare RP2350-Plus

Evaluated 2026-08-11. **Rejected for Rev A.**

The RP2350-Plus offers 26 GPIO against the RP2040-Zero's 20, but it is the RP2350**A**
and still has only **4× 12-bit ADC**. The binding constraint on this design was never
digital pins — it was ADC channels, which is why the second thermistor and the
thermocouple were cut in §4. Six more digital pins buys none of that back.

| Factor | Verdict |
|---|---|
| ADC channels | 4, unchanged — does not solve the actual constraint |
| Digital GPIO | +6, but nothing here needs them |
| Separate SPI for the SD | Not possible: the SD is hard-wired to the display's shared 14-way bus |
| Speed | 150 MHz M33 + FPU vs 133 MHz M0+. Bottleneck is SPI to the display, not the core |
| Board area | Pico form factor ≈ 51 × 21 mm = 1070 mm² vs 423 mm² — **+650 mm²**, a 28 % hit to the non-bus budget |
| Erratum RP2350-E9 | GPIO input-mode leakage up to 120 µA. Into this design's 50 kΩ thermistor source that is meaningless data. Avoidable and fixed in A4 silicon, but a real hazard to introduce for no gain |

**Where it would be worth revisiting:** the RP2350**B** parts carry **8 ADC channels** and
~41 GPIO. That would restore the second thermistor and allow a thermocouple — a genuine
capability increase, and the right trigger for a Rev B. Decide that after using Rev A,
when the missing channels are known rather than guessed.

### Display module, as measured

| | |
|---|---|
| Module PCB | 98.0 × 55.7 mm |
| Mounting holes | 91.5 mm (X) × 49.7 mm (Y) centre-to-centre, Ø3.2 mm |
| Hole insets | 3.0 mm left / 3.5 mm right / 3.0 mm top and bottom — **not centred**, 0.25 mm offset |
| Depth behind screen | 8 mm to the SD slot, **14.5 mm including the pin header** |

The module is **wider than the board and its hole spacing (91.5 mm) exceeds any board
dimension**, so it cannot bolt to the PCB in any orientation. It mounts to the enclosure
instead; H5–H8 were removed. Assume the 14.5 mm depth when designing the enclosure — the
header is staying on.

## 9. Footprints and test points

### Footprint library — complete

`LCM.pretty` holds every non-stock footprint. All were imported from vendor sources and
then **pad-remapped**, because a pad whose name does not match a symbol pin number simply
carries no net — silently, with no error.

| Footprint | Source | Remap applied |
|---|---|---|
| `ACS770_CB_PFF` | Ultra Librarian | 32 stitching vias `4_1…5_16` → `4` / `5` |
| `RP2040_Zero_Castellated` | Ultra Librarian | renumbered to this project's pin order, by signal name |
| `XT60PW-M` / `XT60PW-F` | Ultra Librarian | none needed |
| `XT30PW-M` / `XT30PW-F` | Ultra Librarian | `P`→`1`, `N`→`2` |
| `FPC_05F_14PH20_P0.5mm` | EasyEDA | none needed |
| `SW_TS-1187A_5.1x5.1mm` | EasyEDA | `1,3`→`1`, `2,4`→`2` |
| `TestPoint_D1.5mm`, `RailPad_THT_D1.0mm` | this project | — |
| `MountingHole_M3_3.2mm` | this project | unplated by choice, see below |
| `Potentiometer_Bourns_3362P_Vertical` | this project | stock KiCad name did not resolve; built from the Bourns datasheet |
| `SolderJumper_3_P1.3mm_Open` | this project | stock KiCad name did not resolve; own design |

The ACS770 remap matters most: those 32 perimeter vias are the datasheet's recommended
current-handling stitching. Left as imported they would have been unconnected copper.

### Assembly gotchas found during Rev A bring-up (2026-08-25)

Three things cost an evening each. All are invisible from the schematic.

#### JP1 SHIPS OPEN — the display has no power until you bridge it

`JP1` is a 3-pad solder jumper and it is the display's **only** supply. Pad 2 is
`DISP_VCC` → FPC pin 1; pad 1 is `+5V`, pad 3 is `+3V3`. **Bare copper from fab means the
module is dead**, and the symptom is total: no backlight, no SPI, no I²C, because all
three depend on the module being powered.

**Bridge pad 2 to pad 1 (+5 V).** The module spec calls for 5 V and its own reference
wiring runs VCC = 5 V against 3.3 V logic, which is exactly this case — the module has
onboard level conversion. 3.3 V works but the vendor notes the backlight goes dim.

Verify: pad 2 ↔ pad 1 continuity, pad 2 ↔ pad 3 **open** (bridging all three shorts +5 V
to +3V3), and ~5 V on pad 2 when powered. A blob sitting on soldermask between pads looks
identical to a bridge and conducts nothing.

#### J7 REQUIRES A **TYPE A** (same-side) FFC CABLE

**The cable in the display's box is Type B (opposite-side) and gives a REVERSED pin
order.** Confirmed by continuity and then by a working display once swapped.

With a Type B cable, `J7` pin N lands on module pin 15−N: `DISP_VCC` arrives at the
module's `SD_CS` while `VCC` sits unpowered, and 5 V is driven into a logic pin. The
module survived it, but nothing works and every symptom points at the wrong place.

Order: **14 pin, 0.5 mm pitch, Type A (same side), ≤100 mm.** Sellers also call it
"forward" or "same side"; the `AWM 20624 80C 60V VW-1` marking is a UL wire style printed
on both types and is not a differentiator.

The netlist and footprint are correct — `J7` pin N carries the same signal as module pin
N, and pad 1 is at the normal end. This is purely a cable-type requirement.

#### SW1 / SW2 FOOTPRINT PAD MAPPING IS WRONG — both buttons are dead

`SW_TS-1187A_5.1x5.1mm` was remapped `1,3`→`1`, `2,4`→`2`, which assumes the switch's
internally-connected pairs are 1–3 and 2–4. **They are 1–2 and 3–4.** The remap therefore
ties each net to one pin of *each* internal pair, shorting `BTN1` to `GND` through the
switch's own permanent link.

Confirmed on hardware: **all four pads of both switches read short to GND**, and both pins
sit LOW with the internal pull-ups enabled.

- **Rev B:** correct the remap to the real internal pairing.
- **Rev A bodge:** lift two legs on each switch so only one leg of each internal pair
  remains, on opposite nets — keep 1 and 4, lift 2 and 3. Confirm the pairing on a loose
  switch first.
- **Consequence:** `SW2` is the ZERO/TARE button §6 depends on, so calibration runs from
  serial commands instead. Firmware must not assume the buttons exist.

**Connector gender is not interchangeable.** J1/J2 are male (the input mates the
battery's female half) and J3/J4 female (the output mates the ESC's male half). M and F
have mirrored pads — swapping them reverses polarity.

Everything else uses stock KiCad footprints; see the assignment table in the schematic.

### Mounting

`H1`–`H4` are M3 board mounting holes; `H5`–`H8` are for display-module standoffs and
their positions are **not yet set** — they need the Hosyond module's hole pattern
measured first. All are zero-pin symbols, so they live in the netlist and survive
"Update PCB from Schematic" with *delete extra footprints* enabled.

The holes are **unplated on purpose**. A plated hole tied to GND, with a metal screw in
it, sitting a couple of millimetres from a 60 V bus, is a short waiting for a bad day.
Unplated costs nothing here since the enclosure is printed plastic.

### J6 removed

The 2.54 mm display header duplicated all 14 signals of the FPC connector and cost 35 mm
of board width plus 14 through-holes through the routing space. With the FPC committed
to, it was deleted — symbol, 14 wire stubs and 14 labels. Net count stayed at 38.

### Two things to check physically

1. ~~**RP2040-Zero pad spacing.**~~ **RESOLVED — verified against Waveshare's own
   mechanical drawing.** Every dimension matches:

   | Dimension | Footprint | Waveshare drawing |
   |---|---|---|
   | Board | 18.00 × 23.50 | 18.00 × 23.50 |
   | Side column inset from edge | 1.38 | **1.38** |
   | Side column spacing | 15.24 | 18.00 − 2 × 1.38 |
   | Side column top / bottom inset | 1.59 / 1.59 | **1.59** |
   | Bottom row outer inset | 3.92 / 3.92 | **3.92** |
   | All pitches | 2.54 | **2.54** |

   The `1.38` on the drawing is edge-to-castellation-centre. Note when checking this
   yourself: the two side columns each have a pad on the bottom row's Y coordinate, so a
   naive "pads at y = bottom" query returns 7 pads inset 1.38 mm and appears to
   contradict the 3.92 figure. The true bottom row is 5 pads; 9 + 9 + 5 = 23.

   A community footprint (CountParadox/RP2040-Zero-Kicad) agrees on the same grid, though
   that repo carries a "DO NOT USE" warning from its author — it was used only as a
   cross-check and its file is not in this project.

2. **ACS770 terminal slots.** The two available footprints disagree: Ultra Librarian says
   0.8 mm signal drills and 9.0 × 4.5 mm terminal slots, EasyEDA says 0.91 mm and
   9.5 × 5.0 mm. UL is used here for its stitching vias. Measure a terminal tab when the
   sensor arrives; the slot can be widened without losing the vias.

### Test points

**10 probe pads plus 4 spare rail pads**, in block K of the schematic. They attach by net
label like everything else, so they joined existing nets without creating any — net count
is 38 before and after.

- **Analog / calibration (TP1–TP10):** `PACK+`, `LOAD+`, `+5VS`, `I_RAW`, `I_SENSE`,
  `V5_SENSE`, `VPACK_TAP`, `V_PACK`, `T_NODE`, `T_SENSE`. `I_RAW` and `I_SENSE` either
  side of the divider let you check the scaling directly; `PACK+`/`LOAD+` let you measure
  the board's own IR drop under load with a four-wire setup. This is exactly the set §6
  walks through, which is why they are kept as one block rather than distributed — you
  probe them in sequence with a DMM.
- **Spare rails:** J9 `+3V3`, J10 `+5V`, J11/J12 `GND`, J13 `GP0` — 1.0 mm plated holes,
  so they take a probe ground spring as well as a soldered wire.

**Every probe pad is silkscreened with its NET NAME, not its designator.** During
calibration you are hunting for `I_SENSE` or `T_NODE`, not for "TP5". The grid pitch is
set by the text, not the pads: 9 mm columns give 4.5 mm of clear silk between labels
(`VPACK_TAP` is the longest at ~4.5 mm), and 6 mm rows leave 2.25 mm above each pad's silk
ring. The `silk` stage reads each name off the footprint's own pad net, so it cannot drift
out of step with the netlist.

### Cut from Rev A: TP11–TP27, C12, C13

The original 27 test points plus rail pads had a **501 mm² bounding box — 8.5 % of the
board, and nearly double the area of every resistor and capacitor on it put together.**
The 13 display-bus and 4 user-IO probe points were removed, taking the block to 223 mm²
and recovering 278 mm² (4.7 % of the board) as one contiguous region above U2.

`C12`/`C13`, the button debounce caps, went with them — firmware debounce is more
flexible and SW1/SW2 are not timing-critical.

**What still has probe access.** `SPI_SCK`, `SPI_MOSI`, `SPI_MISO` and `DISP_LED` are
probeable at R11–R14's pads, and `DISP_VCC` at JP1. That matters: §11 flags the microSD
MISO tri-state problem as the risk to test early, and R13 sits in that exact path, so the
diagnosis route is intact.

**What lost it.** `LCD_CS`, `LCD_RS`, `LCD_RST`, `SD_CS` and the four `CTP_*` lines have
no series resistor and no probe pad. They run to J7, which is 0.5 mm pitch and not
practically probeable. If any of those need scoping during bring-up, tack a wire to the
resistor-side via or fit a temporary pad.

> **Why the passive count looks high and is not.** Of 18 resistors, five (R10–R14) are
> 0 Ω placeholders — options to fit later, not circuitry — and R15/R16 are marked
> not-fitted because the RP2040's internal pull-ups are used. Eleven do electrical work:
> five divider legs, three series-protection, two ESC, one thermistor leg. Of the 11
> capacitors, five are the ADC/sensor charge reservoirs the accuracy story depends on
> (§4.3, §4.4) and six are supply decoupling across three rails. All 29 together occupy
> **4.5 % of the board**; the connectors and the two modules take 36 %.

Signal pads are 1.5 mm bare copper with no paste aperture, so reflow leaves them flat and
probe-friendly. All are excluded from BOM and position files.

## 10. Bill of materials

See **`BOM.md`** for the full table with LCSC part numbers, library tier, live stock and
per-line cost, and **`BOM.csv`** for direct upload to JLCPCB.

Summary: 16 SMT lines (10 Basic + 6 Extended), about **$10.84 of parts per board** — of
which the ACS770 alone is $9.98. Everything else together is under a dollar. Nine parts
are hand-soldered: the RP2040-Zero module, four XT connectors, three headers and the trim
pot.

Regenerate with `cd generator && python3 gen_bom.py`; it reads the schematic directly, so
the BOM cannot drift out of sync with the design.

## 11. Firmware architecture

**Toolchain.** Arduino-Pico core (earlephilhower) or PlatformIO. Both handle the RP2040-Zero.

**Sampling (core 1).** ADC in round-robin over ADC0–ADC3 with DMA into a ring buffer.
Oversample and decimate to ~2 kHz effective per channel. Note the RP2040 ADC has known
DNL artefacts near codes 512 / 1536 / 2560 / 3584 on some silicon; averaging 16–64 samples
both fixes that and buys about two extra effective bits.

**UI (core 0).** Display refresh ~20–30 fps, SD writes, button handling, USB CDC output.

**SPI bus sharing.** LCD, touch and SD all hang off SPI0 — all mode 0, so no conflict, but
they want different clocks: LCD 40–62.5 MHz, SD 12–25 MHz. Wrap every access in
`SPI.beginTransaction()` / `endTransaction()` with per-device `SPISettings`. If you use
TFT_eSPI, enable its bus-sharing support rather than letting it own the peripheral.

**Logging.** `SdFat` with a pre-allocated contiguous file and 512-byte buffered writes.
100 Hz CSV is comfortable. Same lines stream over USB CDC so the laptop can capture live.

```csv
millis,v_pack,i_amps,power_w,temp_c,i_peak,p_peak
1042,24.132,87.44,2110.3,41.2,91.06,2198.7
```

**Display.** Rolling current-vs-time graph plus large numerics for V, A, W, and peak-hold
A and W. TFT_eSPI with sprites is lighter and simpler at 480×320; use LVGL only if you
want a real touch UI.

**Buttons.** SW1 cycles display views. SW2 performs the zero/tare of §6.

### Sampling architecture — measured, not assumed

**Added 2026-08-25.** This supersedes the "decimate to ~2 kHz" line above, which was
written before anyone measured what the front end actually passes.

#### Channel bandwidth — the binding constraint

Every channel is analog-limited long before the ADC is. These are the RC corners formed by
each divider's source impedance and its capacitor:

| Channel | Source Z | Cap | **−3 dB** |
|---|---|---|---|
| `I_SENSE` | R1∥R2 = 1.59 k | C4 10 nF | **10.0 kHz** |
| `V5_SENSE` | R5∥R8 = 5.0 k | C6 100 nF | **318 Hz** |
| `V_PACK` | 9.52 k | C5 100 nF | **167 Hz** |
| `T_SENSE` | ~50 k worst case | C7 100 nF | **32 Hz** |

Three consequences that are not obvious from the schematic:

1. **Only `I_SENSE` benefits from fast sampling.** Sampling `V_PACK` above ~2 kHz gains
   nothing — C5 will not let the signal change faster. 100 Hz–1 kHz is ample for all three
   slow channels.
2. **The §4.2 ratiometric correction is only valid below ~318 Hz**, because that is where
   `V5_SENSE` runs out of bandwidth while `I_SENSE` keeps going to 10 kHz. Supply ripple
   faster than that modulates the sensor output and cannot be cancelled. **This is why the
   backlight must be driven solid, never PWM'd** — `analogWrite`'s default ~1 kHz lands
   squarely in that gap. See §14.
3. **`V_PACK` is 60× slower than `I_SENSE`.** The voltage at a peak-current instant is
   smoothed over ~6 ms. Fine for LiPo sag, which develops over tens to hundreds of ms —
   arguably correct, since you want sagged pack voltage rather than switching ripple — but
   it will understate a sub-millisecond event.

#### The split: oversample, decimate, peak-track on the raw stream

```
ADC free-running, DMA, I_SENSE at ~250 kHz, slow channels interleaved at ~1 kHz
        |
        +--> peak tracker    sees EVERY raw sample -> true peaks
        |
        +--> block accumulator, 2 ms
                 mean -> the 500 Hz logged value
                 max  -> that block's peak, with coincident V
```

**Do not sample at 500 Hz.** It aliases anything above 250 Hz and peaks become luck.
500 Hz as a *decimation of a fast stream* is right, and the mean-over-block is itself a
boxcar filter with its first null at 500 Hz — free anti-aliasing.

**250 kHz on `I_SENSE` is the sweet spot.** Worst-case peak under-read of a full-amplitude
10 kHz sinusoid: 4.71 A at 125 kHz, 2.65 A at 167 kHz, **1.18 A at 250 kHz**, 0.30 A at
500 kHz. The sensor floor is ±1.5 A, so past ~250 kHz you are chasing precision the
ACS770 cannot deliver. Peak-track in raw ADC counts and convert once per block.

#### Peak power coincides with peak current

P = I·(V_oc − I·R_int), so dP/dI = 0 at I = V_oc/(2·R_int) — **1260 A** for a 6S pack at
10 mΩ, 630 A at 20 mΩ. Within 0–150 A power rises monotonically with current, so latching
V at the peak-I instant is correct, not an approximation.

#### What "true peak" is worth

Nonlinearity is **±1.5 A fixed at any reading**, noise ±0.225 A. A captured peak is
meaningful to about ±1.5 A no matter how fast you sample. Faster sampling buys the
*timing* of short events, not their amplitude.

500 Hz CSV is ~29 kB/s — comfortable for SdFat with a pre-allocated contiguous file, and
5× what the 100 Hz figure above assumes.

#### Two cores, and why the display does not slow logging

Core 1 samples, core 0 draws. They share only the ADC — which core 0 must never touch
while sampling runs — and negligible memory bandwidth. 250 kHz sampling, 500 Hz logging
and a 60 fps display coexist. Demonstrated in `display_bringup`, where moving the graph
sampler to core 1 took it from ~25 Hz to a solid 77.6 Hz.

#### Display refresh ceiling

Full-frame redraw is bandwidth-bound: 300 kB per frame, so 4.9 fps at 12 MHz and 25 fps
even at 62.5 MHz. **Partial updates are limited by per-call overhead instead**, and that is
where the speed is:

| Approach | Calls/frame | Ceiling |
|---|---|---|
| Per-pixel/segment ink-only | ~1550 | 43 fps |
| One window-write per column | ~390 | 172 fps |
| **ST7796 hardware scroll + one new column** | ~2 | effectively free |

The ST7796 has a hardware vertical scroll (`0x33` VSCRDEF / `0x37` VSCRSADD), and at
rotation 1 the panel's **native vertical axis is the graph's time axis** — so a scrolling
plot becomes one register write per frame, with the fixed top/bottom areas landing exactly
on the left/right label margins. Arduino_GFX does not expose those commands; they would go
through the databus directly. That is the route to a 60 fps standalone camera mode.

### Known risk to test early
The microSD on these display modules shares MISO with the LCD. Some cheap modules do not
tri-state the SD's MISO cleanly when `SD_CS` is high, which corrupts LCD reads. **Verify
this before trusting logged data.** If it misbehaves, R13 is already in the MISO path as a
0 Ω placeholder and can become a series resistor or a buffer.

---

## 12. Files and KiCad version

| File | Purpose |
|---|---|
| `Logging_Current_Meter.kicad_sch` | The schematic |
| `LCM.kicad_sym` | All project symbols — fully self-contained |
| `sym-lib-table` | Resolves the `LCM:` nickname |
| `Logging_Current_Meter.kicad_pro` | Project file |
| `sheet_preview.png` | Rendered preview |
| `generator/` | The Python that produced all of it, plus the verifier |

**Format is now KiCad 10.** The files on disk are:

| File | Format version | Last written by |
|---|---|---|
| `Logging_Current_Meter.kicad_sch` | `20260306` | eeschema 10.0 |
| `Logging_Current_Meter.kicad_pcb` | `20260206` | pcbnew 10.0 |
| `LCM.kicad_sym` | `20231120` | the generator |

KiCad refuses to open files newer than itself, so **KiCad 10 or newer is now required**;
an older install will not open the project at all.

The original generator output was KiCad 8 (`20231120`), chosen because it sits below
KiCad 9's ceiling and is read natively by 8, 9 and 10, which made the generated files
portable to whatever KiCad happened to be installed. That mattered while the schematic was
machine-generated. KiCad 10 has since opened, accepted and rewritten both files, and that
bump is one-way.

`generator/kicad8.py` still hardcodes `SCH_VERSION = 20231120` and
`GENERATOR_VERSION = "8.0"`. **Re-running `gen_sch.py` would therefore downgrade the
schematic and discard every edit made in KiCad since.** Treat it as the script that
produced Rev A, not as a tool to run again. `gen_pcb.py` was updated for KiCad 10 and
emits placed KiCad 10 footprint blocks; `gen_sch.py` was not.

Every symbol lives in `LCM.kicad_sym` on purpose. If the schematic referenced stock
libraries, KiCad could re-link a symbol to a stock version whose pin geometry differs from
what the schematic was generated against, silently pulling pins off their wire stubs.
Self-contained removes that failure mode. Swap to `Device:R` and friends later if you
prefer — the netlist does not care.

### Verifying it yourself

```bash
cd generator
python3 gen_sch.py ..        # regenerate everything
python3 verify.py ../Logging_Current_Meter.kicad_sch ../LCM.kicad_sym
```

`verify.py` re-reads the finished files from disk and rebuilds the netlist
**geometrically** — pin connection points, wire endpoints and label anchors that share a
coordinate are one node — then compares it against an independently written expectation
of all 38 nets and 155 pin connections. It also re-checks the ACS770 terminal list, the
display pin order and the RP2040 pin map by *name*, so a transposition cannot hide behind
a pin number that happens to line up. It currently passes clean.

What that does **not** prove: that KiCad's own ERC is happy, or that the file is
byte-perfect KiCad 8 syntax. Those need KiCad itself. Open it, run ERC, and tell me what
it says.

---

## 13. Schematic conventions

Connectivity is by **net label on a short stub at every pin**, not by long point-to-point
wires. This is a normal "signal name" style, it keeps the sheet readable at A2, and it
makes the netlist a pure function of the label table rather than of routing geometry —
which is what allows the machine verification above.

Blocks A–J on the sheet are annotated with the reasoning behind each design choice, so the
schematic stands on its own without this document open beside it.

---

## 14. Layout plan

### Board and stackup

| | |
|---|---|
| Outline | 95 × 50 mm, corners R2 |
| Layers | 4: F.Cu / In1.Cu / In2.Cu / B.Cu |
| Copper | 1 oz outer, 0.5 oz inner (JLCPCB standard 1.6 mm) |
| F.Cu | Positive bus (exposed), components, signals |
| In1.Cu | **GND plane** — negative return and the reference for every signal above it |
| In2.Cu | Signals and +3V3 / +5V distribution |
| B.Cu | Negative bus (exposed) + GND pour |

Both buses run vertically (top edge to bottom edge) as F.Cu + B.Cu pours stitched with a
dense via field, soldermask removed on both sides, sized for a 10 AWG bar along each.

### Regions

As built. Coordinates are board-local millimetres, origin at the top-left corner; the
authoritative table is `PLACEMENT` in `generator/gen_pcb.py`.

**Generated** by `generator/region_map.py`, read straight off the `.kicad_pcb` — do not
edit by hand. The hand-maintained version of this map drifted twice: it was still showing
`TP27`, `C12`, `C13`, `D2`, `R18` and the old column grid long after every one of those had
gone. A label is allowed at most one row of give from the part's true position; anything
that will not fit is reported rather than moved, so the map cannot quietly misplace a part.

```
  u=0                                                                u=95
   +----------------------------------------------------------------------------+ v=0
   |                                                                            |
   |                                                                            |
   |  H1                     J2        TP1    TP2    TP3    TP4    TP5     H2   |
   |                                                                            |
   |                                   TP6    TP7    TP8    TP9   TP10          |
   |            J1                                                              |
   |                                                                            |
   |                                   J9     J10    J11    J12    J13          |
   |                               D1                                           |
   |                                          C4 C5  C7 C6                      |
   |                                          R2 R7  R9 R8                      |
   |                                                                            |
   |                                   C3 R1            R5                      |
   |                                U1    C1                       U2           |
   |                                   FB1    C2                                |
   |                                                                            |
   |                                                                            |
   |                                     C10          RV1                       |
   |                           R3 R4             R10       C8 C9 C11 R14 R17    |
   |            J3                                            R12        J8     |
   |                                  R6              J5   R11   R13            |
   |                                                                            |
   |                         J4         R15     R16      JP1                    |
   |                                                                            |
   |  H3                                  SW1     SW2          J7          H4   |
   |                                                                            |
   |                                                                            |
   +----------------------------------------------------------------------------+ v=62
        CURRENT BLOCK  u <= 42.5        ELECTRONICS  u >= 43
```

> **Known DRC warning: D1 / U1 courtyards overlap by 3.49 × 0.45 mm.** D1 is hand-placed
> at (40.94, 20.00) rot 180. The overlap is courtyard *margin* only — checked, and there is
> no U1 pad, no fab body and no silk inside D1's footprint area; U1's package body starts
> at v = 24 and its nearest terminal pad at v = 21.5. KiCad will still flag it. Nudging D1
> up 0.5 mm clears it if you want a silent DRC.

- **U1 rotated 90°** puts its two terminals (natively side by side, 10 mm apart) into a
  vertical stack, so the current direction is the board's short axis. The 24 mm body then
  projects **right**, landing VIOUT on pin 3 at u = 41.5, directly beside column A of the
  analog front end.
- **J1 and J3 sit at u = 16.5**, which places pin 1 at **u = 20.10 — exactly U1's terminal
  column**. The positive path is a straight vertical drop with no lateral jog. Their GND
  pins land at u = 12.90, giving a second straight run down the left edge.
- **The XT30 taps are not on the 150 A bus.** They are a 30 A convenience and reach GND
  through the In1 plane like any other component, which frees them from the bus channels
  and lets them clear the XT60 bodies.
- **SW1/SW2 are on the bottom edge**, not buried in the analog block — SW2 is pressed by
  hand during every tare.
- **RV1** is 7.5 × 7.15 mm, far too big for the 3 mm analog column pitch, so it sits below
  the block where a screwdriver still reaches it.
- **H1/H3 sit inside the GND channel**, which is harmless: a screw there is at the
  measurement reference. H2/H4 are in the electronics area, well clear of the 60 V bus.

- **U1 rotated 90°** so its terminals align with the current direction, body projecting
  right so the signal pins land nearest the analog section — a short `VIOUT` run.
- **U2 USB-C must reach the right edge.**
- **J7 FPC** near an edge so the ribbon exits cleanly.
- **RV1** reachable with a screwdriver once assembled.
- **H1–H4** at the corners, inset clear of the bus pours.
### The analog front end is lanes, not a grid

The four ADC inputs are **consecutive pads on U2's top row**, all at v = 22.38:

| U2 pad | Net | u |
|---|---|---|
| 7 | `I_SENSE` | 76.42 |
| 6 | `V_PACK` | 78.96 |
| 5 | `T_SENSE` | 81.50 |
| 4 | `V5_SENSE` | 84.04 |

Rev A filled a 3-column grid function-by-function. It read tidily on the schematic but
meant all four of those nets had to leave a column *vertically* and then cross the whole
board *horizontally*, through each other and through C10 and RV1. That is what made the
board hard to route.

So the block is transposed. Each channel gets a horizontal lane, and **the lanes are
ordered top-to-bottom to match U2's pad order left-to-right**, which makes the four runs
parallel and non-crossing by construction:

```
  row 1  v = 20.5   ADC pin caps       C4    C5    C7    C6     <- nearest free lane to U2
  row 2  v = 24.5   last series part   R2    R7    R9    R8
  row 3  v = 28.5   upstream          C3 R1 D1          R5
  row 4  v = 32.5   sensor supply     FB1 C1 C2
                    u = 54.0  58.5  63.0  67.5
```

- **Row 1** holds the charge reservoirs that make the high-impedance dividers work at all
  (§4.3, §4.4), so they take the lane closest to U2. The four runs are 19–25 mm, straight,
  parallel, and `routability.py` confirms **zero crossings** between them.
- **Row 2** holds each chain's last element. R2/R8 are divider lower legs; R7 is the fault
  limiter that caps the clamp current if 60 V ever reaches `VPACK_TAP` through a low
  impedance (§4.3), and R9 the thermistor series — protection belongs at the MCU end, not
  at the source.
- **C3** is the 10 nF datasheet maximum on VIOUT, 3.5 mm from U1 pin 3 — as close as U1's
  courtyard allows.
- **The pack-voltage divider stays down on the LOAD+ pour it taps** (R3/R4 at v = 42.5),
  so the only 60 V net in the electronics half is one short hop from the pour into R3.
  `VPACK_TAP` then runs up to R7/D1/C5. That costs 31 mm of MST on a 9.5 kΩ node — which
  is free electrically and belongs on In2.Cu — and in exchange keeps the high voltage out
  of the signal lanes entirely.

Measured by `generator/routability.py` (Manhattan MST per net, poured nets excluded):
**968 mm total against 1058 mm, −8.5 %.** The headline number understates it; the four
analog channels are where it landed:

| Net | Before | After |
|---|---|---|
| `T_NODE` | 91.9 mm | **53.4 mm** |
| `V5_SENSE` | 91.6 mm | **61.3 mm** |
| `V_PACK` | 66.1 mm | **52.0 mm** |
| `T_SENSE` | 52.0 mm | **38.5 mm** |
| `T_POT_TOP` | 19.5 mm | **6.0 mm** |
| `I_SENSE` | 66.0 mm | **58.9 mm** |
| `VPACK_TAP` | 28.4 mm | 59.9 mm — deliberate, see above |

### Display and touch constants — determined on hardware 2026-08-25

| Constant | Value | How it was found |
|---|---|---|
| `LCD_ROTATION` | **1** | the intended viewing orientation |
| `TOUCH_INVERT_X` | **0** | |
| `TOUCH_INVERT_Y` | **0** | |
| SPI clock | 12 MHz for bring-up | panel takes 40–62.5 MHz |
| Backlight | **solid HIGH, never PWM** | see §11 — ~1 kHz PWM sits in the gap where the ratiometric correction cannot cancel it |

> **The ground truth for touch mapping is the crosshair landing under the finger**, not a
> verbal description of where a touch was. Both the touch read and the drawing land in the
> same frame, so if it tracks, it is right. Reasoning from "I touched the top-left" once
> produced a confidently mirrored mapping, because the description was in the viewer's
> frame while the rendered image sits 180° from it.
>
> Note that rotation 3 with both inverts at 0 is the *same touch maths* as rotation 1 with
> both at 1 — but rotation 3 also rotates the **display** 180°. That is why the inverts
> exist separately from `LCD_ROTATION`, and why they must be re-checked if it changes.

The FT6336U also needs configuring for responsiveness. Register `0x86` (ID_G_CTRL) allows
monitor mode **by default**, and `0x87` drops into it after **30 seconds** idle, where the
panel scans slowly and the first touch back is late or lost. Write `0x86 = 0x00` to forbid
it and `0x88 = 0x04` for the fastest scan period. `CTP_INT` on GP13 works as an interrupt;
the ISR must only set a flag, since an I²C transaction inside an ISR would deadlock.

### Passive designators are on Dwgs.User

27 resistor and capacitor designators on a 95 × 62 board is more silkscreen than it is
worth — they crowd the pads and collide at this density. All 23 non-placeholder R/C
references moved to **`Dwgs.User`** (KiCad's "User.Drawings"), where they still print on
documentation and stay visible while editing but leave the physical silk clean.

`Dwgs.User` rather than `F.Fab`, because these footprints already carry an
`fp_text user "${REFERENCE}"` on F.Fab — moving the property there would print the
designator twice on the fab drawing.

> **The five 0 Ω placeholders keep their silkscreen: R10–R14.** These are the parts most
> likely to be changed by hand on an assembled board — R10 becomes 91k for a stable
> thermistor trim, R11–R14 become 22R if the display bus rings, and R13 in particular is
> the one you will be reaching for if the microSD MISO problem in §11 is real. You cannot
> rework a part you cannot find. Detected by `Value == "0R"` read off the board, not from
> a list in the generator.

Everything that is not a resistor or capacitor keeps its silk: D1, FB1, RV1, the
connectors, switches, mounting holes, test points, U1 and U2.

### Net classes

| Class | Nets | Clearance | Notes |
|---|---|---|---|
| `HV_BUS` | `PACK+`, `LOAD+` | **0.5 mm** | Exposed pour, 60 V |
| `GND_BUS` | `GND` | **0.5 mm** | Exposed pour + In1 plane |
| `PWR` | `+3V3`, `+5V`, `+5VS` | 0.2 mm | 0.5 mm tracks |
| `Default` | everything else | 0.2 mm | 0.25 mm tracks |

Vias 0.6/0.3 mm (0.8/0.4 on the bus classes); edge clearance 0.5 mm.

> **0.5 mm, not the 2.0 mm rev A specified.** The ACS770's two terminals are **1.00 mm
> apart** — u [17.85, 22.35], v [21.50, 30.50] and v [31.50, 40.50] — which is the moulded
> part, not something layout can change. A 2 mm copper clearance is therefore an
> unsatisfiable DRC error on every board built.
>
> The 2 mm was never an electrical requirement: rev A's own note says *"IPC-2221 only
> demands ~0.4 mm at 60 V — the 2 mm is for the assembly reality of flooding exposed
> copper with solder"*. That reasoning is right, but it applies to the **soldermask
> apertures**, which is where molten solder can actually flow — not to the copper. So the
> copper takes 0.5 mm (comfortably above IPC) and the apertures are laid out ≥ 2 mm apart,
> which `verify_pcb.py` check 6 enforces.

### Pours, as built

| Zone | Net | Layers | Extent (board-local) |
|---|---|---|---|
| GND plane | `GND` | In1.Cu | whole board, inset 0.8 mm |
| GND bus | `GND` | F.Cu + B.Cu | u [0.5, 15.5], full height |
| PACK+ bus | `PACK+` | F.Cu + In2.Cu + B.Cu | u [17.6, 33.0], v [0.5, 30.7] |
| LOAD+ bus | `LOAD+` | F.Cu + In2.Cu + B.Cu | u [17.6, 33.0], v [31.3, 61.5] |

The two channel outlines are 2.1 mm apart. PACK+ and LOAD+ stop 0.2 mm clear of their
respective ACS770 terminal groups, leaving 0.6 mm between them — tight, but it is the
part's own geometry and the 0.5 mm clearance permits it.

**180 stitching vias** (0.8/0.4 mm) on a 2.5 mm grid: 96 on GND, 43 on PACK+, 41 on
LOAD+. Each is placed only where it clears every foreign pad by 1.6 mm; `verify_pcb.py`
check 6 independently confirms none lands on a pad of another net, which would be a dead
short no amount of zone clearance would save you from.

### Why the board file is built by KiCad first

The stock footprints (0805, SOT-23, headers, pot, electrolytic, solder jumper) live in the
KiCad installation, not in this project, so the board cannot be generated from scratch
here. The sequence is:

1. Open the PCB editor and run **Tools → Update PCB from Schematic (F8)**. KiCad creates
   the board in its own native format and pulls in every footprint. *This also serves as
   the outstanding check that all stock footprint names resolve.* **Done** — all 82
   footprint names resolved.
2. Save. The file lands in this folder.
3. Placement, outline, zones, keepouts and rules are then applied by editing that file —
   the same approach used on the schematic, so nothing hand-placed ever gets overwritten.

### `generator/gen_pcb.py` — what it has done

The board file is **KiCad 10 native (`20260206`)**. The schematic has since caught up and
is now `20260306`, also KiCad 10. Both were written by KiCad itself, and there is nothing
to gain from forcing either back to the generator's `20231120`.

| Stage | Effect |
|---|---|
| `sync` | Added `RV1` and `JP1`, which were put in the schematic after the last F8, from `LCM.pretty` with their nets and their schematic symbol uuid. 80 → **82** footprints |
| `prune` | Removes footprints no longer in the schematic, **and** any whose library ID the schematic has reassigned — those are dropped so `sync` rebuilds them, which is what F8 does. J8 went 1x04 → 1x03 this way |
| `renet` | Renames pad nets the schematic has renamed. `prune`/`sync` reconcile which *footprints* are on the board and touch nothing on the ones that survive, so U2 pin 10 sat on the dead `/ESC_TELEM_MCU` until this stage existed |
| `silk` | Labels each probe pad with its net name and hides its designator |
| `refdes` | Moves R/C designators to `Dwgs.User`, keeping the five 0 Ω placeholders on silk |
| `pour` | In1 GND plane, three bus zones, six soldermask openings, 180 stitching vias |
| `stackup` | 2 → **4 copper layers** (F.Cu / In1.Cu / In2.Cu / B.Cu). Netclasses `HV_BUS`, `GND_BUS` (2.0 mm clearance) and `PWR` (0.5 mm track) with pattern assignments, plus the DRC minimums, into `.kicad_pro` |
| `outline` | Edge.Cuts **95 × 62 mm, R2 corners**, board origin at page (50, 50) |
| `place` | All **63** footprints to the `PLACEMENT` table |

Every stage is idempotent and takes a timestamped backup. Re-run the lot with
`cd generator && python3 gen_pcb.py ..`.

> **No explicit `(stackup)` block was written.** KiCad synthesises a default 4-layer
> 1.6 mm stackup on open. Set the 1 oz outer / 0.5 oz inner copper weights in
> **Board Setup → Physical Stackup** — they are a fab note, not something DRC consumes.

### Two format assumptions, now confirmed

These were the only things in the board file not confirmed against a KiCad-written
example, and both were load-bearing. **Both are now verified.** KiCad 10 opened the board,
accepted it without complaint, and rewrote it as format `20260206` with
`(generator "pcbnew") (generator_version "10.0")`. A KiCad-written file is exactly the
evidence that was missing.

1. **Inner copper layer ordinals.** Assumed KiCad 9 renumbered the layer enum so copper
   takes the even ordinals: F.Cu = 0, B.Cu = 2, and every even ordinal above 2 unused, so
   In1.Cu = 4 and In2.Cu = 6. **Confirmed.** The saved file contains `F.Cu`, `In1.Cu`,
   `In2.Cu` and `B.Cu`, and Board Setup reads four copper layers.
2. **Zone and via net syntax.** Written as `(net "GND")` by name rather than the KiCad 6–8
   `(net 1) (net_name …)` pair. **Confirmed.** The saved file still has no top-level
   `(nets …)` section for an index to resolve against, and KiCad preserved the name form
   on its own write. The published format docs at dev-docs.kicad.org predate this change
   and could not settle it; the file itself now does.

Had either been wrong, KiCad would have refused the file and named the offending line, the
same way it caught the quoted-tag bug: noisy, not silent, and a one-line fix.

### Verifying the board

```bash
cd generator
python3 verify_pcb.py ../Logging_Current_Meter.kicad_pcb ../Logging_Current_Meter.kicad_sch
python3 render_pcb.py ../Logging_Current_Meter.kicad_pcb /tmp/pcb.svg
```

`verify_pcb.py` is to the board what `verify.py` is to the schematic: it re-reads the
finished file off disk and re-derives every position from it, so it can disagree with the
generator. It checks **quoted tags** (below), the footprint inventory against the
schematic, that every electrical pad carries a net, that every pad clears the board edge,
and that **no two courtyards overlap**. Footprints with no `F.CrtYd` at all —
`SW_TS-1187A`, the FPC connector — fall back to their pad extent rather than being
silently exempted from the overlap check.

> **The quoted-tag trap.** Every s-expression tag must be a *bare* token. The first build
> of `gen_pcb.py` emitted `("uuid" "…")` instead of `(uuid "…")`, because the helper that
> serialises the tree quotes any plain Python string and only leaves a `Sym` bare. The
> file parses perfectly with any reasonable reader, the diff looks right, and KiCad
> refuses to open the board at all:
>
> ```
> Expecting layer, hide, effects, locked, render_cache or tstamp.
> Got 'quoted string' … line 14731, offset 5.
> ```
>
> Every tag `gen_pcb.py` emits now goes through the `S()` helper, and `verify_pcb.py`
> greps for `("…"` as check 0 — it is the cheapest check and it fails the whole file, so
> it runs before anything else.

Check 5 fails on any board net the schematic no longer declares — the check that caught
`/ESC_TELEM_MCU` still sitting on U2 pin 10 after the rename. Check 7 fails on any
component sitting inside a soldermask opening, which caught R3 placed in the middle of the
LOAD+ exposed strip, where solder flooding would have swamped it. The bus terminals
themselves (J1–J4, U1) are exempt by name, since the apertures exist to expose the copper
around them — listed explicitly rather than inferred from "has a pad on this net", because
R3 taps LOAD+ too and still has to be caught.

`routability.py` estimates copper cost so a claim that one placement routes better than
another can be checked: per net it builds a Manhattan minimum spanning tree over the pad
centres and sums the edges. Poured nets (GND, the two bus nets, and the In2 power rails)
are excluded — their MST says nothing useful.

Current state: **clean.** 62 footprints, 37 nets, 0 courtyard overlaps. The 10 pads
reported as netless are connector shroud legs and FPC hold-down tabs, which correctly
carry no net; the check distinguishes them by the absence of a `pinfunction`.

> **The empty-property trap.** Both this file and `gen_pcb.py` read "which schematic
> symbols have a footprint" by walking paren-balanced symbol blocks, never by a regex
> pairing `"Reference"` with the next `"Footprint"`. That regex runs straight past any
> symbol whose footprint is empty — every power flag on this sheet — and pairs its
> reference with the *following* symbol's footprint. The first `prune` did exactly that
> and deleted six live parts (C1, J11, R4, R10, R11, TP9) before the count check caught
> it.

### Schematic surgery

`strip_sch.py` removes symbols together with the wire stubs and net labels that belong to
them. It does not hardcode stub geometry: it reads each symbol's pin offsets out of
`lib_symbols`, removes only wires that actually end on a pin point, then removes labels
sitting at the far end of those wires. Leave a stub behind and you have an orphan label
still declaring a net; take one too many and a real connection vanishes silently.
`verify.py` is the check on all of it, and passes.

It also discovers the block K grid origin from TP1's live position rather than assuming
`add_testpoints.py`'s original coordinates — the whole block has since been dragged in
KiCad by (−198.12, −53.34), and hardcoding would have flung the rail pads back across the
sheet, undoing hand placement that §12 exists to protect.

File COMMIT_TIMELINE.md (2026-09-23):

# Detailed Commit Timeline

The complete account of every commit, newest first. Commit messages stay short
and scannable; this file holds the full detail — what changed in each file, why,
how it was verified, and what remains open. Entries are grouped by version where
the project has one, otherwise by date, so a section can be lifted into release
notes with light editing.

<!-- Newest entries go directly below this line. -->

## v3.6 — 2026-09-23

### firmware: v3.6 — cycle mode replaces direction; profiles are plain pulses
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

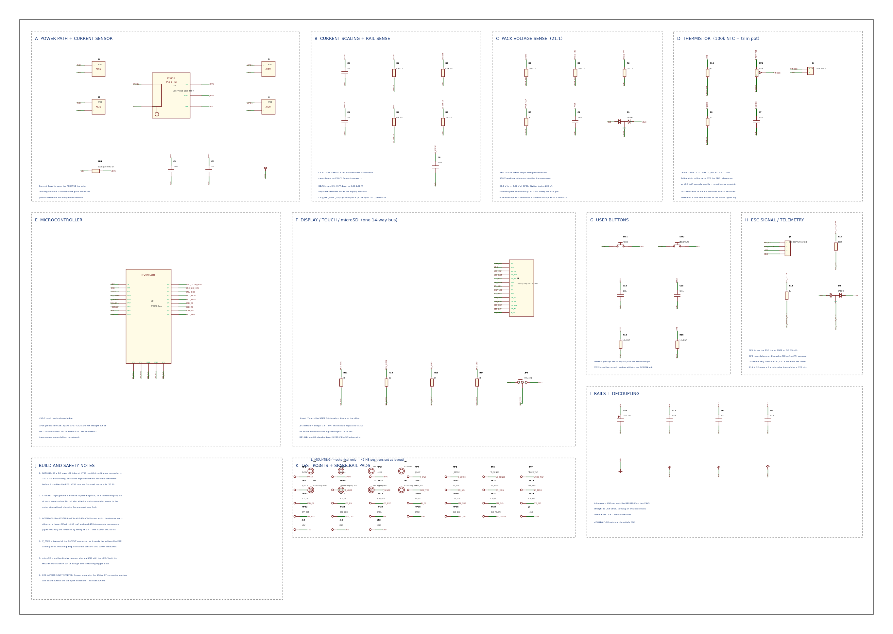
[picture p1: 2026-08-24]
sheet_preview.png

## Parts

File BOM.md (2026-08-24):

# Bill of Materials

ESC Test Bench Mainboard, Rev A. Generated from `Logging_Current_Meter.kicad_sch`.

**All LCSC part numbers below were read off jlcpcb.com/parts on 2026-07-27.** None are from memory. Stock and library tier change constantly — re-check both before you order.

## 1. SMT parts — what the pick-and-place places

| Ref | Qty | Value | Package | LCSC | MFR part | Tier | Stock | $ ea | $ line |
|---|---|---|---|---|---|---|---|---|---|
| C1, C5, C6, C7, C9, C11 | 6 | 100n | 0805 | `C49678` | CC0805KRX7R9BB104 | Basic | 22,583,308 | 0.0321 | 0.1926 |
| C2, C8 | 2 | 10u | 0805 | `C1713` | CL21A106KOQNNNE | Extended | 2,367,318 | 0.0820 | 0.1640 |
| C3, C4 | 2 | 10n | 0805 | `C83170` | CC0805KRX7R9BB103 | Extended | 1,163,183 | 0.0183 | 0.0366 |
| C10 | 1 | 100u 16V | SMD D6.3x5.4mm | `C970684` | RVT1C101M0605 | Extended | 35,452 | 0.0328 | 0.0328 |
| D1 | 1 | BAT54S | SOT-23 | `C12765` | LBAT54SLT1G | Extended | 230,864 | 0.0196 | 0.0196 |
| FB1 | 1 | 600R@100MHz 2A | 0805 | `C1017` | GZ2012D601TF | Basic | 560,191 | 0.0286 | 0.0286 |
| J7 | 1 | Display 14p FPC 0.5mm | FPC 14P 0.5mm | `C2856800` | FPC-05F-14PH20 | Extended | 3,170 | 0.1166 | 0.1166 |
| R1 | 1 | 2.4k 1% | 0805 | `C17526` | 0805W8F2401T5E | Basic | 439,194 | 0.0036 | 0.0036 |
| R2 | 1 | 4.7k 1% | 0805 | `C17673` | 0805W8F4701T5E | Basic | 7,616,330 | 0.0109 | 0.0109 |
| R3, R4 | 2 | 100k 1% | 0805 | `C149504` | 0805W8F1003T5E | Basic | 6,358,740 | 0.0103 | 0.0206 |
| R5, R6, R8 | 3 | 10k 1% | 0805 | `C17414` | 0805W8F1002T5E | Basic | 15,940,626 | 0.0109 | 0.0327 |
| R7, R9 | 2 | 1k | 0805 | `C17513` | 0805W8F1001T5E | Basic | 9,329,211 | 0.0050 | 0.0100 |
| R10, R11, R12, R13, R14 | 5 | 0R | 0805 | `C17477` | 0805W8F0000T5E | Basic | 8,472,397 | 0.0100 | 0.0500 |
| R17 | 1 | 100R | 0805 | `C17408` | 0805W8F1000T5E | Basic | 8,218,245 | 0.0103 | 0.0103 |
| SW1, SW2 | 2 | TS-1187A-B-A-B | SMD 5.1x5.1mm | `C318884` | TS-1187A-B-A-B | Basic | 1,363,977 | 0.0204 | 0.0408 |
| U1 | 1 | ACS770KCB-150U-PFF-T | CB-5 PFF | `C499454` | ACS770KCB-150U-PFF-T | Extended | 336 | 9.9813 | 9.9813 |

**10 Basic + 6 Extended unique parts.** Parts cost ≈ **$10.75/board**, of which $9.98 is the ACS770 alone — everything else together is about $0.77.

JLCPCB charges a one-off feeder setup fee (roughly $3) per unique **Extended** part; Basic parts are free. With 6 Extended lines that is about $18 on the first order.

### Notes on specific lines

- **`C1017`** (GZ2012D601TF) — 500 mA / 300 mOhm is ample; this rail carries only the sensor's ~14 mA
- **`C12765`** (LBAT54SLT1G) — BAT54**S** — the SERIES variant, pin 3 the common node. BAT54/A/C are NOT substitutes: with GND on pin 1 and +3V3 on pin 2 only the series part forms a two-way rail clamp on V_PACK. Fit a BAT54C by mistake and the clamp does nothing
- **`C970684`** (RVT1C101M0605) — SMD aluminium electrolytic, 6.3 x 5.4 mm, 16 V
- **`C83170`** (CC0805KRX7R9BB103) — no Basic 10 nF 0805 exists; this one has 1.1 M in stock
- **`C1713`** (CL21A106KOQNNNE) — no Basic 10 uF 0805 exists; Samsung, 2.3 M in stock
- **`C499454`** (ACS770KCB-150U-PFF-T) — the expensive line. Only 336 in stock -- buy early. See note on mounting. Marked *not for new designs*: **ACS772KCB-150U-PFF-T is a drop-in replacement needing no board changes** -- same package, same 26.66 mV/A, same V_CC/10 quiescent, same ratiometric behaviour, same 4.7 kOhm / 10 nF load limits. See DESIGN.md 4.1.1
- **`C2856800`** (FPC-05F-14PH20) — bottom-contact, hinged lid. Verify contact side against your FPC cable.
- **`C318884`** (TS-1187A-B-A-B) — 5.1 x 5.1 mm SMD tactile, 1.5 mm actuator, 1.6 N

## 2. Not fitted

| Ref | Value | Why |
|---|---|---|
| R15, R16 | 10k | Button pull-ups. The RP2040's internal pull-ups are used; these are footprint-only fallbacks. |

## 3. Hand-soldered — not placeable

| Ref | Part | Package | Note |
|---|---|---|---|
| J1 | XT60PW-M | THT, board-mount male | Amazon / HobbyKing. High-current, hand-solder. |
| J2 | XT30PW-M | THT, board-mount male | Amazon / HobbyKing. |
| J3 | XT60PW-F | THT, board-mount female | Amazon / HobbyKing. |
| J4 | XT30PW-F | THT, board-mount female | Amazon / HobbyKing. |
| J5 | 1x2 2.54 mm header | THT | NTC probe pads. |
| J8 | 1x3 2.54 mm header | THT | AM32 ESC servo header: signal / +5V (NOT connected) / GND. |
| RV1 | JIERR 3362P-1-104 — LCSC `C48997913` | THT trimmer, 100k, top adjust | 100 kOhm, 0.5 W, 7 x 6.8 mm, ~$0.19 @ 5, 30,920 in stock. Footprint was the wrong 3362 variant (pads in a row); rebuilt from the vendor EasyEDA model as the 3362P triangle — pins 1/3 5.08 mm apart, pin 2 offset 2.54 mm. Run Update Footprints from Library, then re-route T_NODE and T_POT_TOP. See DESIGN.md §4.4. |
| U2 | Waveshare RP2040-Zero | 23-pad castellated module | Buy direct from Waveshare / Amazon. Not in the JLCPCB library. |

Plus, off-board: the Hosyond 3.5" ST7796U display module and a 100k B3950 NTC probe.

## 4. Board features, not parts

| Ref | Note |
|---|---|
| JP1 | 3-pad solder jumper — bare copper, nothing to place. |
| J13 | GP0 expansion pad — plated hole, nothing to place. |
| H1–H8 (8) | M3 mounting hole — unplated, mechanical only. |
| TP1–TP27 (27) | Probe pad — bare copper. |
| J9–J12 (4) | Spare rail pad — plated hole, nothing to place. |

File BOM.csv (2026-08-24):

Comment | Designator | Footprint | LCSC Part #
100n | C1,C5,C6,C7,C9,C11 | Capacitor_SMD:C_0805_2012Metric | C49678
10u | C2,C8 | Capacitor_SMD:C_0805_2012Metric | C1713
10n | C3,C4 | Capacitor_SMD:C_0805_2012Metric | C83170
100u 16V | C10 | Capacitor_SMD:CP_Elec_6.3x5.4 | C970684
BAT54S | D1 | Package_TO_SOT_SMD:SOT-23 | C12765
600R@100MHz 2A | FB1 | Inductor_SMD:L_0805_2012Metric | C1017
Display 14p FPC 0.5mm | J7 | LCM:FPC_05F_14PH20_P0.5mm | C2856800
2.4k 1% | R1 | Resistor_SMD:R_0805_2012Metric | C17526
4.7k 1% | R2 | Resistor_SMD:R_0805_2012Metric | C17673
100k 1% | R3,R4 | Resistor_SMD:R_0805_2012Metric | C149504
10k 1% | R5,R6,R8 | Resistor_SMD:R_0805_2012Metric | C17414
1k | R7,R9 | Resistor_SMD:R_0805_2012Metric | C17513
0R | R10,R11,R12,R13,R14 | Resistor_SMD:R_0805_2012Metric | C17477
100R | R17 | Resistor_SMD:R_0805_2012Metric | C17408
TS-1187A-B-A-B | SW1,SW2 | LCM:SW_TS-1187A_5.1x5.1mm | C318884
ACS770KCB-150U-PFF-T | U1 | LCM:ACS770_CB_PFF | C499454

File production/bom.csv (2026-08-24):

Designator | Footprint | Quantity | Value | LCSC Part #
C1, C11, C5, C6, C7, C9 | 0805 | 6 | 100n | C49678
C10 | CP_Elec_6.3x5.4 | 1 | 100u 16V | C970684
C2, C8 | 0805 | 2 | 10u | C1713
C3, C4 | 0805 | 2 | 10n | C83170
D1 | SOT-23 | 1 | BAT54S | C12765
FB1 | 0805 | 1 | 600R@100MHz 2A | C1017
J7 | FPC_05F_14PH20_P0.5mm | 1 | Display 14p FPC 0.5mm | C2856800
JP1 | SolderJumper_3_P1.3mm_Open | 1 | 5V / 3V3
R1 | 0805 | 1 | 2.4k 1% | C17526
R10, R11, R12, R13, R14 | 0805 | 5 | 0R | C17477
R17 | 0805 | 1 | 100R | C17408
R2 | 0805 | 1 | 4.7k 1% | C17673
R3, R4 | 0805 | 2 | 100k 1% | C149504
R5, R6, R8 | 0805 | 3 | 10k 1% | C17414
R7, R9 | 0805 | 2 | 1k | C17513
RV1 | RES-ADJ-TH_3362P | 1 | 100k
SW1 | SW_TS-1187A_5.1x5.1mm | 1 | MODE | C318884
SW2 | SW_TS-1187A_5.1x5.1mm | 1 | ZERO/TARE | C318884
U1 | SENSOR-TH_ACS758KCB-150B-PFF-T (1) | 1 | ACS770KCB-150U-PFF-T | C499454

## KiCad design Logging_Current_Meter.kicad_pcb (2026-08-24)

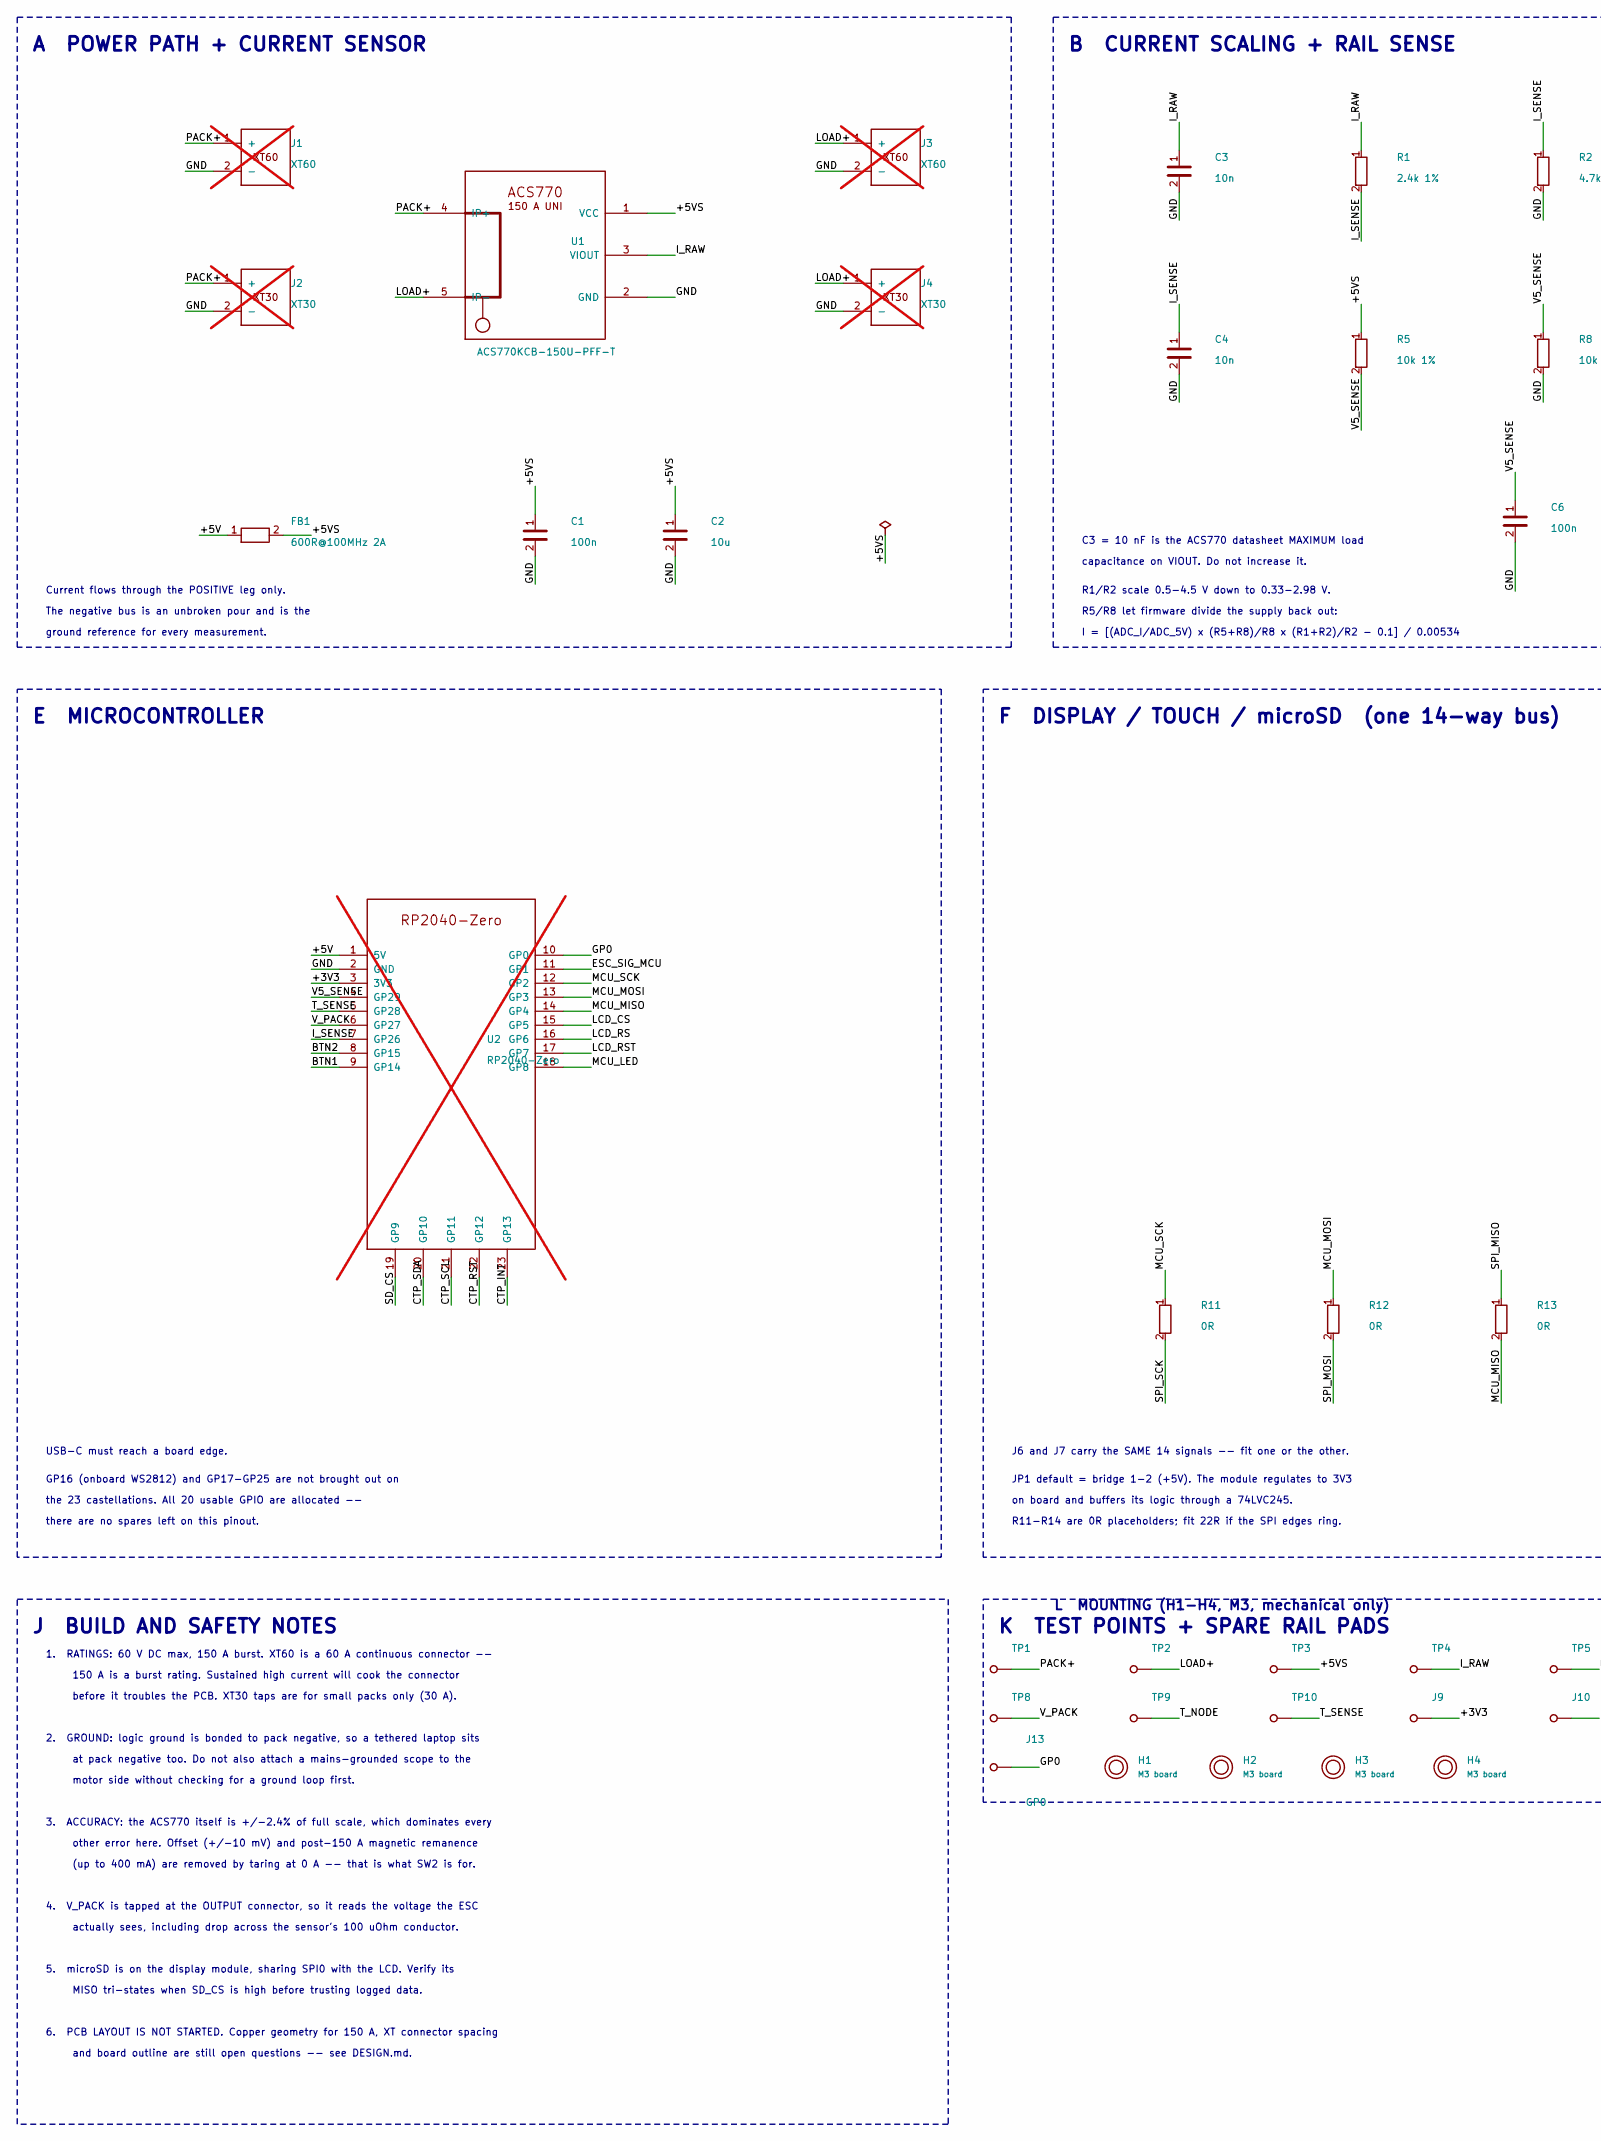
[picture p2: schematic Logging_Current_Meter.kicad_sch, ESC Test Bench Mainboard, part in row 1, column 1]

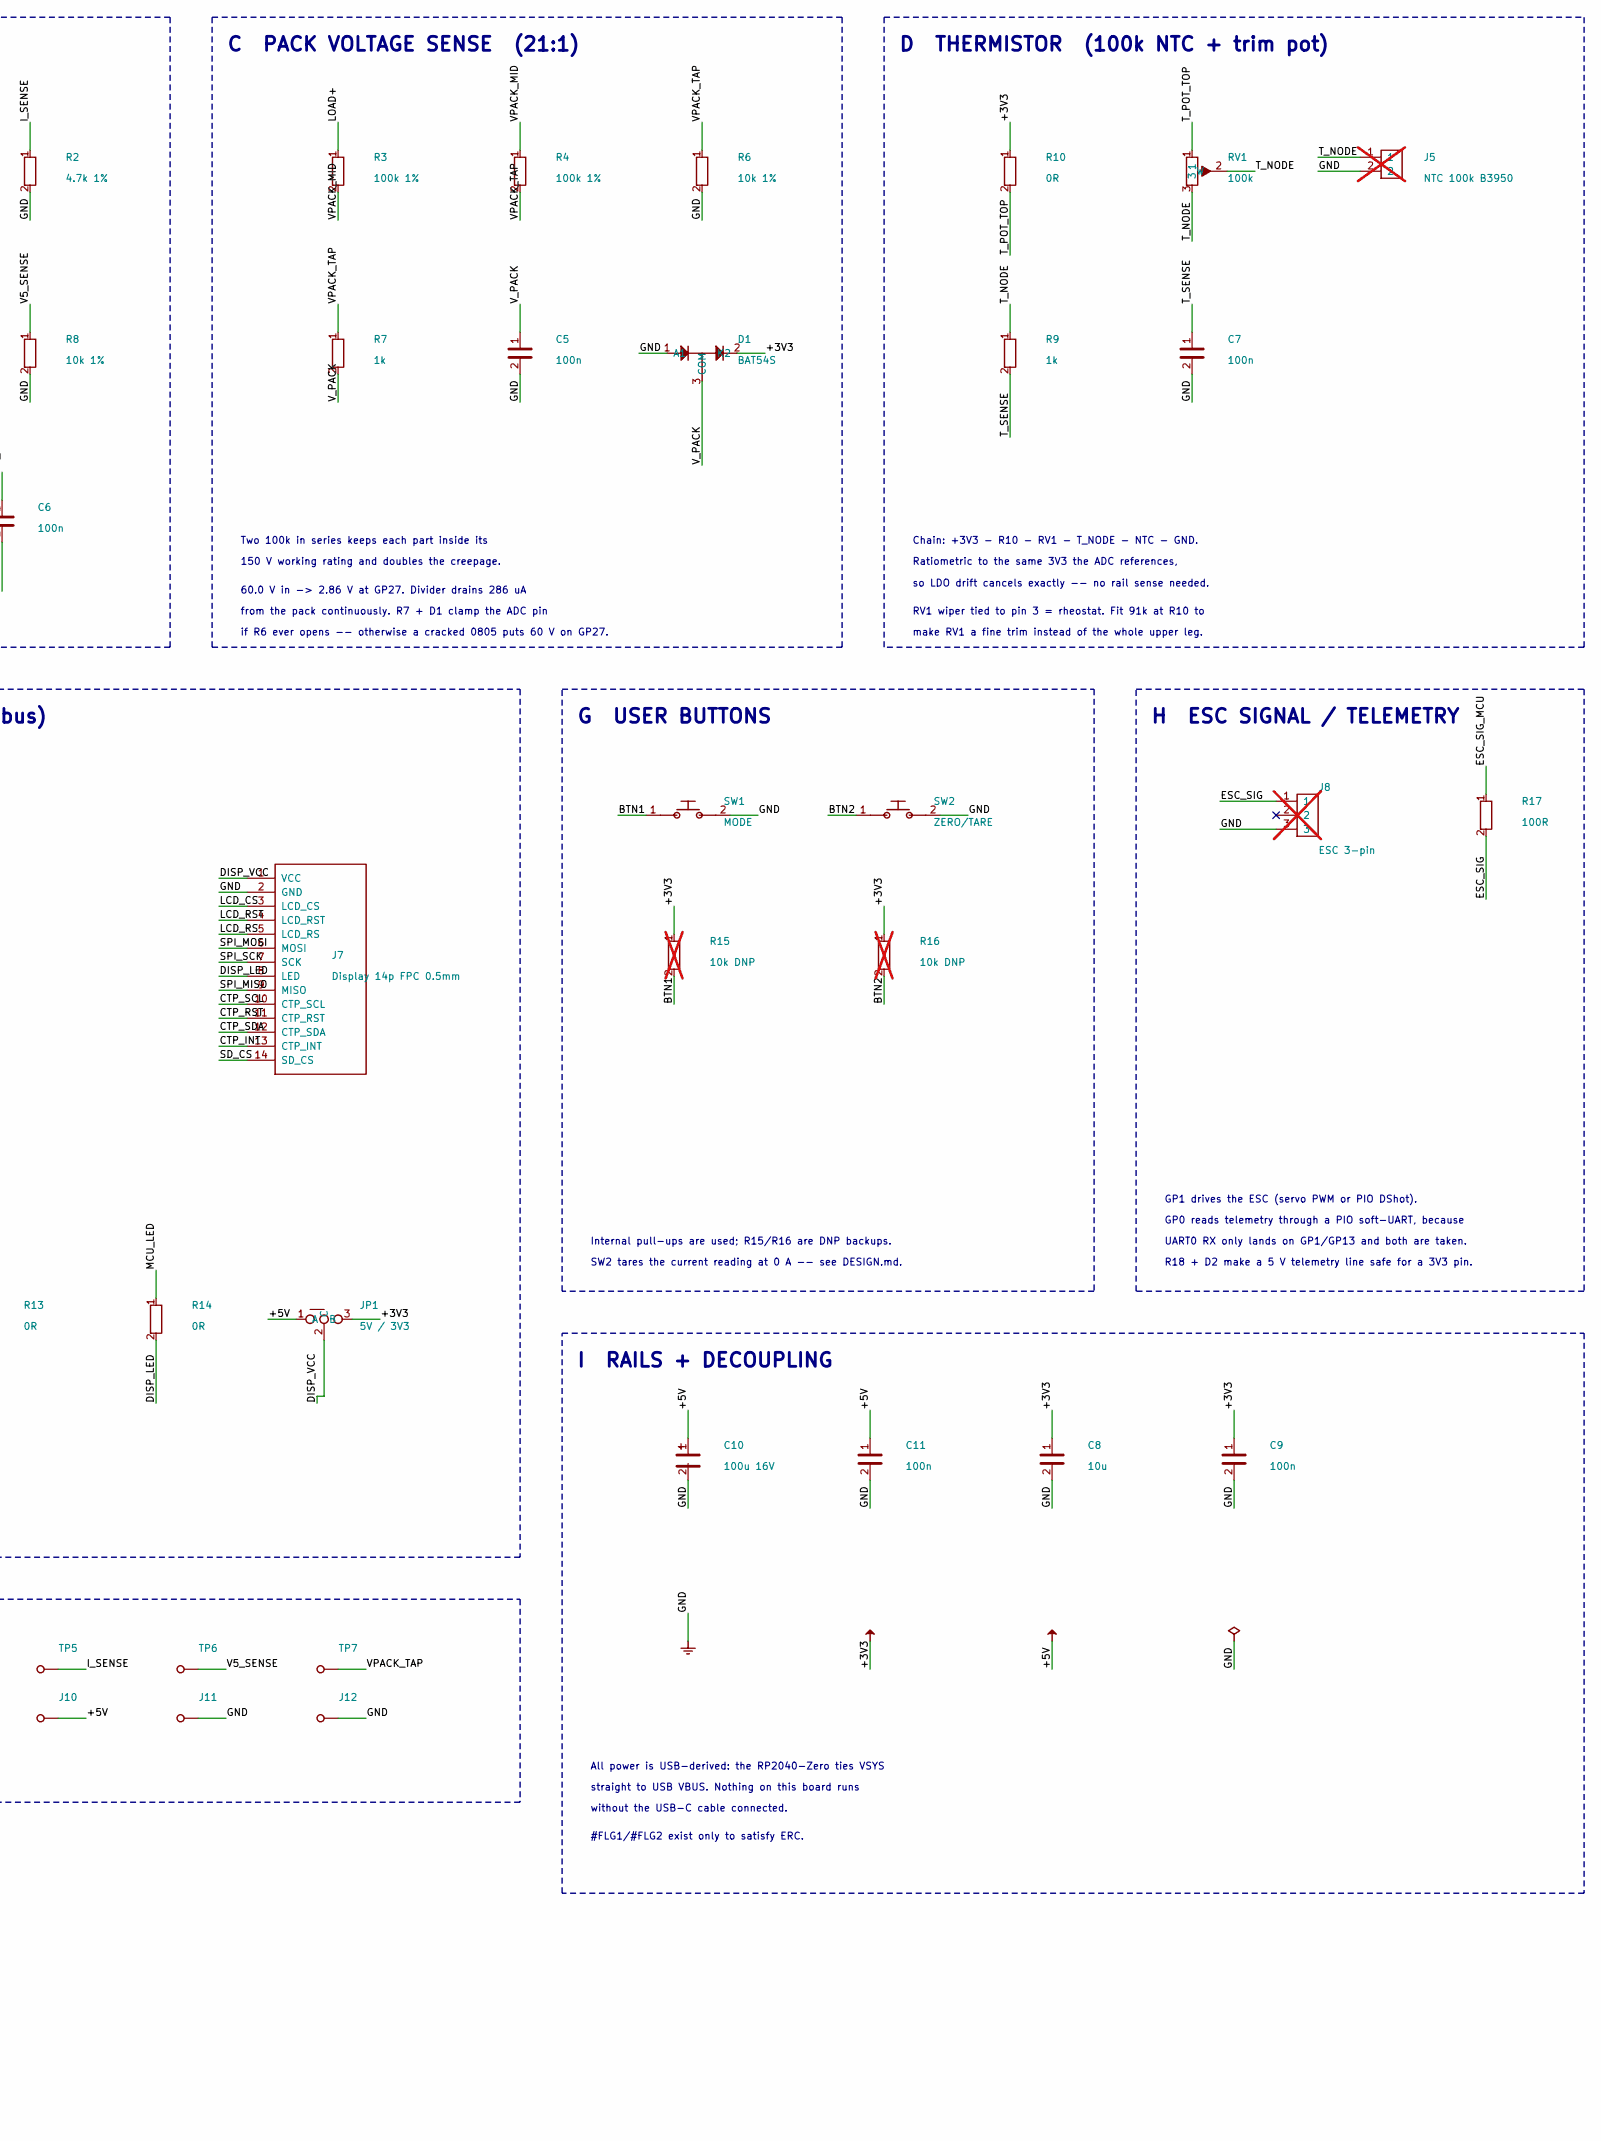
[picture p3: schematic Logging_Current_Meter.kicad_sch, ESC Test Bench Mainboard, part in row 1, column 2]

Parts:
C1, C5, C6, C7, C9, C11: 100n; C_0805_2012Metric; LCSC C49678
C2, C8: 10u; C_0805_2012Metric; LCSC C1713
C3, C4: 10n; C_0805_2012Metric; LCSC C83170
C10: 100u 16V; CP_Elec_6.3x5.4; LCSC C970684
D1: BAT54S; SOT-23; LCSC C12765
FB1: 600R@100MHz 2A; L_0805_2012Metric; LCSC C1017
H1, H2, H3, H4: M3 board; MountingHole_M3_3.2mm
J1: XT60; XT60PW-M; MPN XT60PW-M; not fitted
J2: XT30; XT30PW-M; MPN XT30PW-M; not fitted
J3: XT60; XT60PW-F; MPN XT60PW-F; not fitted
J4: XT30; XT30PW-F; MPN XT30PW-F; not fitted
J5: NTC 100k B3950; PinHeader_1x02_P2.54mm_Vertical; not fitted
J7: Display 14p FPC 0.5mm; FPC_05F_14PH20_P0.5mm; LCSC C2856800
J8: ESC 3-pin; PinHeader_1x03_P2.54mm_Vertical; not fitted
J9: +3V3; RailPad_THT_D1.0mm
J10: +5V; RailPad_THT_D1.0mm
J11, J12: GND; RailPad_THT_D1.0mm
J13: GP0; RailPad_THT_D1.0mm
JP1: 5V / 3V3; SolderJumper_3_P1.3mm_Open
R1: 2.4k 1%; R_0805_2012Metric; LCSC C17526
R2: 4.7k 1%; R_0805_2012Metric; LCSC C17673
R3, R4: 100k 1%; R_0805_2012Metric; LCSC C149504
R5, R6, R8: 10k 1%; R_0805_2012Metric; LCSC C17414
R7, R9: 1k; R_0805_2012Metric; LCSC C17513
R10, R11, R12, R13, R14: 0R; R_0805_2012Metric; LCSC C17477
R15, R16: 10k DNP; R_0805_2012Metric; LCSC C17414; not fitted
R17: 100R; R_0805_2012Metric; LCSC C17408
RV1: 100k; Potentiometer_Bourns_3362P_Vertical
SW1: MODE; SW_TS-1187A_5.1x5.1mm; LCSC C318884
SW2: ZERO/TARE; SW_TS-1187A_5.1x5.1mm; LCSC C318884
TP1: PACK+; TestPoint_D1.5mm
TP2: LOAD+; TestPoint_D1.5mm
TP3: +5VS; TestPoint_D1.5mm
TP4: I_RAW; TestPoint_D1.5mm
TP5: I_SENSE; TestPoint_D1.5mm
TP6: V5_SENSE; TestPoint_D1.5mm
TP7: VPACK_TAP; TestPoint_D1.5mm
TP8: V_PACK; TestPoint_D1.5mm
TP9: T_NODE; TestPoint_D1.5mm
TP10: T_SENSE; TestPoint_D1.5mm
U1: ACS770KCB-150U-PFF-T; ACS770_CB_PFF; MPN ACS770KCB-150U-PFF-T; LCSC C499454
U2: RP2040-Zero; RP2040_Zero_Castellated; MPN RP2040-Zero; not fitted

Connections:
+3V3: C8.1, C9.1, D1.2 (K2), J9.1 (1_1), JP1.3 (B), R10.1, R15.1, R16.1, U2.3 (3V3)
+5V: C10.1 (+), C11.1, FB1.1, J10.1 (1_1), JP1.1 (A), U2.1 (5V)
/+5VS: C1.1, C2.1, FB1.2, R5.1, TP3.1 (1_1), U1.1 (VCC)
/BTN1: R15.2, SW1.1, U2.9 (GP14)
/BTN2: R16.2, SW2.1, U2.8 (GP15)
/CTP_INT: J7.13 (CTP_INT), U2.23 (GP13)
/CTP_RST: J7.11 (CTP_RST), U2.22 (GP12)
/CTP_SCL: J7.10 (CTP_SCL), U2.21 (GP11)
/CTP_SDA: J7.12 (CTP_SDA), U2.20 (GP10)
/DISP_LED: J7.8 (LED), R14.2
/DISP_VCC: J7.1 (VCC), JP1.2 (C)
/ESC_SIG: J8.1, R17.2
/ESC_SIG_MCU: R17.1, U2.11 (GP1)
/GP0: J13.1 (1_1), U2.10 (GP0)
/I_RAW: C3.1, R1.1, TP4.1 (1_1), U1.3 (VIOUT)
/I_SENSE: C4.1, R1.2, R2.1, TP5.1 (1_1), U2.7 (GP26)
/LCD_CS: J7.3 (LCD_CS), U2.15 (GP5)
/LCD_RS: J7.5 (LCD_RS), U2.16 (GP6)
/LCD_RST: J7.4 (LCD_RST), U2.17 (GP7)
/LOAD+: J3.1 (+), J4.1 (+), R3.1, TP2.1 (1_1), U1.5 (IP-)
/MCU_LED: R14.1, U2.18 (GP8)
/MCU_MISO: R13.2, U2.14 (GP4)
/MCU_MOSI: R12.1, U2.13 (GP3)
/MCU_SCK: R11.1, U2.12 (GP2)
/PACK+: J1.1 (+), J2.1 (+), TP1.1 (1_1), U1.4 (IP+)
/SD_CS: J7.14 (SD_CS), U2.19 (GP9)
/SPI_MISO: J7.9 (MISO), R13.1
/SPI_MOSI: J7.6 (MOSI), R12.2
/SPI_SCK: J7.7 (SCK), R11.2
/T_NODE: J5.1, R9.1, RV1.2 (W), RV1.3, TP9.1 (1_1)
/T_POT_TOP: R10.2, RV1.1
/T_SENSE: C7.1, R9.2, TP10.1 (1_1), U2.5 (GP28)
/V5_SENSE: C6.1, R5.2, R8.1, TP6.1 (1_1), U2.4 (GP29)
/VPACK_MID: R3.2, R4.1
/VPACK_TAP: R4.2, R6.1, R7.1, TP7.1 (1_1)
/V_PACK: C5.1, D1.3 (COM), R7.2, TP8.1 (1_1), U2.6 (GP27)
GND: C1.2, C2.2, C3.2, C4.2, C5.2, C6.2, C7.2, C8.2, C9.2, C10.2 (-), C11.2, D1.1 (A1), J1.2 (-), J2.2 (-), J3.2 (-), J4.2 (-), J5.2, J7.2 (GND), J8.3, J11.1 (1_1), J12.1 (1_1), R2.2, R6.2, R8.2, SW1.2, SW2.2, U1.2 (GND), U2.2 (GND)

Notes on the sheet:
GP1 drives the ESC (servo PWM or PIO DShot).
R1/R2 scale 0.5-4.5 V down to 0.33-2.98 V.
F DISPLAY / TOUCH / microSD (one 14-way bus)
motor side without checking for a ground loop first.
R5/R8 let firmware divide the supply back out:
6. PCB LAYOUT IS NOT STARTED. Copper geometry for 150 A, XT connector spacing
L MOUNTING (H1-H4, M3, mechanical only)
if R6 ever opens -- otherwise a cracked 0805 puts 60 V on GP27.
B CURRENT SCALING + RAIL SENSE
C3 = 10 nF is the ACS770 datasheet MAXIMUM load
1. RATINGS: 60 V DC max, 150 A burst. XT60 is a 60 A continuous connector --
Two 100k in series keeps each part inside its
D THERMISTOR (100k NTC + trim pot)
SW2 tares the current reading at 0 A -- see DESIGN.md.
The negative bus is an unbroken pour and is the
actually sees, including drop across the sensor's 100 uOhm conductor.
G USER BUTTONS
60.0 V in -> 2.86 V at GP27. Divider drains 286 uA
make RV1 a fine trim instead of the whole upper leg.
there are no spares left on this pinout.
4. V_PACK is tapped at the OUTPUT connector, so it reads the voltage the ESC
C PACK VOLTAGE SENSE (21:1)
straight to USB VBUS. Nothing on this board runs
before it troubles the PCB. XT30 taps are for small packs only (30 A).
other error here. Offset (+/-10 mV) and post-150 A magnetic remanence
UART0 RX only lands on GP1/GP13 and both are taken.
150 V working rating and doubles the creepage.
All power is USB-derived: the RP2040-Zero ties VSYS
ground reference for every measurement.
Chain: +3V3 - R10 - RV1 - T_NODE - NTC - GND.
150 A is a burst rating. Sustained high current will cook the connector
H ESC SIGNAL / TELEMETRY
R18 + D2 make a 5 V telemetry line safe for a 3V3 pin.
K TEST POINTS + SPARE RAIL PADS
#FLG1/#FLG2 exist only to satisfy ERC.
on board and buffers its logic through a 74LVC245.
the 23 castellations. All 20 usable GPIO are allocated --
at pack negative too. Do not also attach a mains-grounded scope to the
Ratiometric to the same 3V3 the ADC references,
USB-C must reach a board edge.

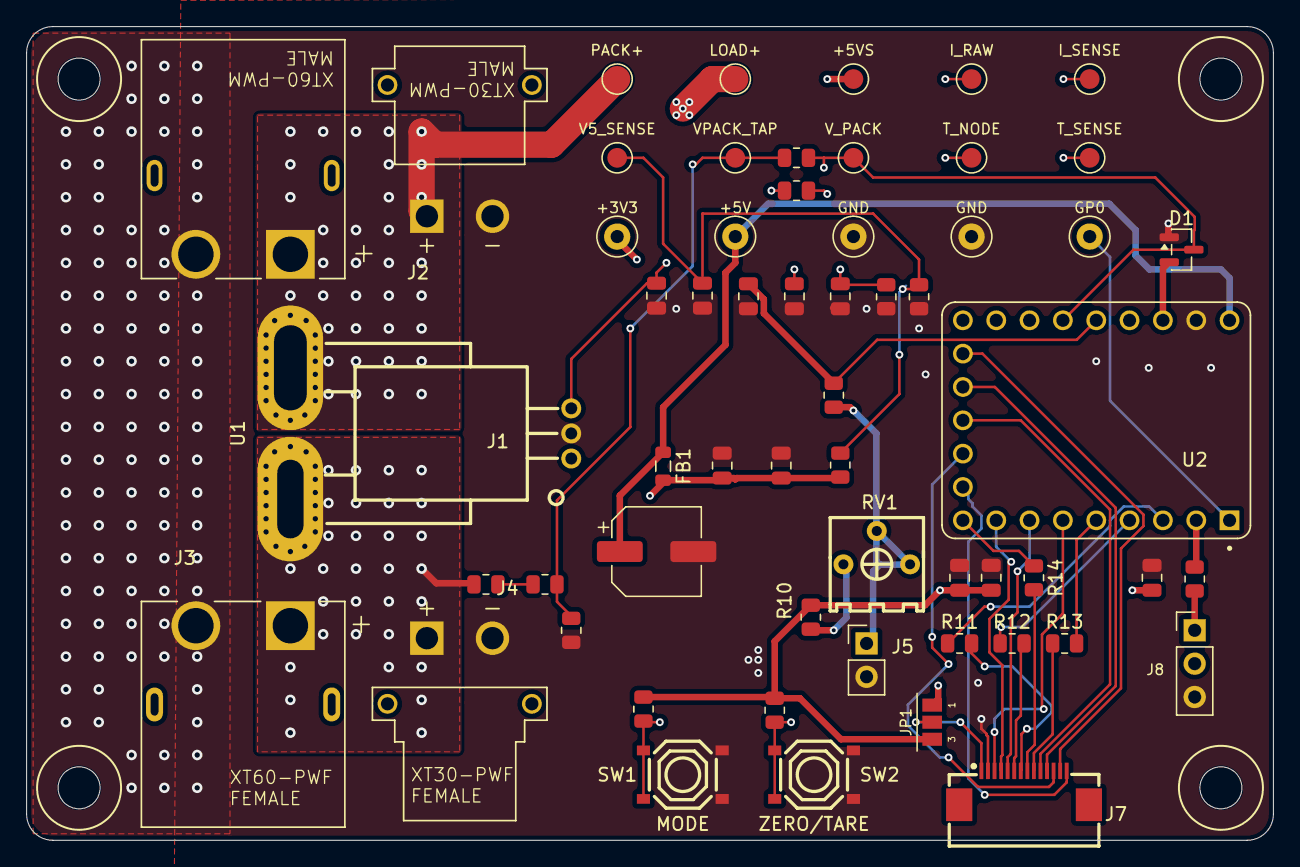
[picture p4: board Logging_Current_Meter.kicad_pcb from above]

Board: 4 copper layers, 95.0 x 62.0 mm, 62 parts (0 on the bottom side), 37 nets.

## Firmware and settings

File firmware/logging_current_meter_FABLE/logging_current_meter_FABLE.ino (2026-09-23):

/* ==========================================================================
 * logging_current_meter_FABLE.ino — v3.6 (2026-09-23)
 *
 * Touchscreen UI for the Just 'Cuz Robotics Logging Current Meter (Rev A).
 * RP2040-Zero + 3.5" 480x320 ST7796/FT6336U on one FPC.
 *
 * This file is wiring only. Everything else lives in a module beside it:
 *
 *   Config.h      pins, bus rates, sampling cadence, calibration constants
 *   Theme.h       palette and fonts
 *   Layout.h      every pixel coordinate, and the touch targets
 *   Format.*      fixed-point value formatters
 *   Sampler.*     core-1 ADC, calibration maths, graph history ring
 *   Widgets.*     button chrome, cached fields, toast
 *   Settings.*    user settings and their flash persistence
 *   Clock.*       wall clock for log timestamps (host unit-tested)
 *   EscOut.*      ESC output + motion engine (manual, ramped cycle, Log Test)
 *   EscProfile.h  pure cycle-profile maths (host unit-tested)
 *   Logger.*      SD CSV logging, triggers, USB CSV stream
 *   Version.h     the version string shared by banner and log headers
 *   Screens.*     navigation and dispatch
 *   Screen*.cpp   one file per screen
 *
 * Display, touch and text come from the JCR_TouchScreen library.
 *
 * --------------------------------------------------------------------------
 * THE CONTRACT — the rules that keep touch reliable as this grows
 *
 *   CORE 1 is the instrumentation core. It owns the FT6336U and the ADC, and
 *   nothing else. It services touch at a fixed 200 Hz, and runs the 13.158 ms
 *   sampling tick with touch servicing interleaved BETWEEN the four channel
 *   bursts — so the ~5 ms of oversampling can never delay a touch sample by
 *   more than one channel (~1.3 ms).
 *
 *   CORE 0 owns the display and all UI logic. It drains queued touch events
 *   every pass and repaints incrementally.
 *
 *   1. Core 1 must never block, print or draw. Sampling and servicing only.
 *   2. Core 0 may be arbitrarily slow. A slow frame delays the REACTION to a
 *      tap, never its REGISTRATION — events queue, and overflow is counted.
 *   3. Never repaint the whole screen per tick. Chrome once on entry, then
 *      only the fields that changed. See the note atop Widgets.h for the
 *      forceClear rule that goes with cached fields.
 *   4. Core 0 never touches the ADC; core 1 never touches SPI or the display.
 *
 * --------------------------------------------------------------------------
 * Version history
 *   v3.6  2026-09-23  Cycle profiles are plain pulse values. The DIRECTION
 *                     tile (FWD / REV / FWD+REV, which mirrored the high
 *                     pulse about neutral) is replaced by CYCLE MODE:
 *                     STOP -> SPIN locks the low end to the ESC type's stop
 *                     pulse and frees SPIN US across 1000-2000, so a
 *                     bidirectional ESC runs backwards by setting it below
 *                     1500 — what is on the screen is what is on the pin;
 *                     SPIN -> SPIN frees both ends, in either order, for
 *                     cycling between two running points, easing from the
 *                     pre-roll's idle into the low end over the ramp-up time.
 *                     Settings blob v7 folds an old REV profile's direction
 *                     into its stored pulse so the motor keeps turning the
 *                     way it did; changing ESC type resets the cycle's low
 *                     end to the new type's stop pulse.
 *   v3.5  2026-09-23  ESC handling on the bench. Every run — cycle or Log
 *                     Test — starts with a pre-roll at idle, settable in
 *                     Settings (ESC PRE-ROLL, 0-15 s, default 5 s), because an
 *                     ESC ignores throttle until it has finished beeping and a
 *                     run that began at once jerked into its first ramp.
 *                     START now works with the output already live: it
 *                     commands neutral and pre-rolls rather than refusing.
 *                     The header button escalates ARM -> STOP (idle, signal
 *                     still up, so the next run skips the ESC's start-up) ->
 *                     CUT (output off); holding it for a second cuts from any
 *                     state. A finished Log Test holds neutral instead of
 *                     disarming, with a 30 s fuse that cuts it if the bench is
 *                     left alone. Settings blob v5 (migrates v4/v3/v2/v1).
 *   v3.4  2026-09-23  Wall clock, since the board has no RTC: epoch base plus
 *                     millis(), set on Settings -> CLOCK -> SET CLOCK or over
 *                     serial with `c` (epoch seconds, or a typed date; the
 *                     laptop's capture_stream.py syncs it on connect). Saved
 *                     into the settings blob at log boundaries, on SAVE, when
 *                     set, and every 5 min while idle — never while a log
 *                     records or the ESC is live. Logs gain a `# clock` header
 *                     line and `stopped=` on the end line; the analyzer shows
 *                     the start time and says when the clock may be behind.
 *                     Settings blob v4.
 *   v3.3  2026-09-22  Test Mode rework. Three tabs — MANUAL, CYCLE, LOG TEST —
 *                     under one header with a STOP that cuts the output from
 *                     anywhere. ESC type UNI (arm/idle 1000 us) or BIDI
 *                     (arm/neutral 1500 us, FWD/REV/FWD+REV cycles). Manual:
 *                     steppers with hold-to-repeat, or a tap/drag slider
 *                     with HOLD or DEAD-MAN release (dead-man also releases
 *                     on a lost UP or 60 ms of stale touch data). Cycle: a
 *                     saved profile with linear ramps (0-3000 ms) and dwells
 *                     (500-15000 ms), edited via tiles + one editor row.
 *                     Log Test: LOG_n_TEST_V.CSV, 3 s pre-roll, N cycles, 5 s
 *                     post-roll, auto-disarm. Hold-to-repeat (1 s, then 5/s)
 *                     on every stepper. Settings blob v3 (migrates v2/v1).
 *                     JCR_TouchScreen 1.2.0 adds lastGoodSampleMicros().
 *   v3.2a 2026-09-16  Log files are named LOG_<n>_<MODE>_<V>V.CSV (n counts
 *                     up from the highest on the card; V is the pack voltage
 *                     at the start, or the resting voltage just before a
 *                     current trigger). LOG MODE uses arrow buttons and wraps
 *                     round in both directions.
 *   v3.2  2026-09-16  ESC OUTPUT WAS WRONG SINCE v3.1. arduino-pico clamps
 *                     analogWriteFreq() to >= 100 Hz without saying so, so
 *                     the 50 Hz frame ran at 100 Hz on a 20000-count range
 *                     and every pulse came out at half width (1000 us idle
 *                     was 500 us). The ESC pin now uses the core's Servo
 *                     library (PIO, writeMicroseconds, fixed 50 Hz — the
 *                     frame-period stepper is gone), and
 *                     arming always emits idle for 2 s before anything else
 *                     (the old 'e' key armed at 1500 us). New: SD logging
 *                     (LOG screen — manual, Test-cycle, or current-threshold
 *                     start with a 1-15 min duration and 0.5 s pre-trigger;
 *                     raw + filtered V/I, energy since log start) and a USB
 *                     CSV stream of the same rows without energy. All
 *                     non-data serial output is now prefixed '#'. Settings
 *                     blob v2, migrating a v3.1c save.
 *   v3.1c 2026-09-08  First harness data: the FT6336U's mode register (0xA4)
 *                     was found drifting 47 times in 39 min and being
 *                     rewritten by the watchdog — the likely cause of the
 *                     fade, and the reason it "works a lot better" now. The
 *                     watchdog now counts drift per register (to tell a
 *                     resetting part from a flaky register) and checks every
 *                     500 ms. Navy classic palette (0x0020 was the green
 *                     LSB, not blue); Test Mode rows re-spaced; Dev Mode's
 *                     crosshair restores what it drags across.
 *   v3.1b 2026-09-08  DISPLAY WAS COLOUR-INVERTED SINCE v2.0. The IPS panel
 *                     needs INVON; the GFX firmware set it via its `ips`
 *                     flag, the JCR driver sent INVOFF. Every palette since
 *                     v2.0 was judged as its complement. Fixed in the
 *                     library (ips flag, default on) + LCD_IPS in Config.h.
 *                     Also a touch-responsiveness harness for chasing the
 *                     fade-after-a-minute report: tap latency, worst frame,
 *                     controller register watchdog + reinit, core-1 tick
 *                     health, a 1 s serial telemetry line, and serial keys
 *                     to bisect at the bench (see Serial below).
 *   v3.1a 2026-09-08  Test Mode / Settings UI fixes. The Russo One headers had
 *                     been generated with a reduced charset, so '+', '/', ','
 *                     and '%' were zero-width and silently dropped — the pulse
 *                     steppers read "-50 -10 -10 -50". Regenerated with those
 *                     glyphs (heights unchanged, so no layout drift). Three
 *                     labels that overflowed their boxes were measured and
 *                     re-fitted, stepper +/- became vector bars instead of a
 *                     5x7 speck, and PAL_DARK's borders went brighter, not
 *                     dimmer: with no box fill the strokes carry all the
 *                     structure, and dim ones left a flat wash.
 *   v3.1  2026-09-08  Test Mode (ESC signal, manual set point + auto-cycle on
 *                     hardware PWM), Settings screen, runtime themes with a
 *                     genuinely dark palette, and a tunable weighted moving
 *                     average on the V and I readings. The Calibrate screen
 *                     is gone — it only showed compile-time constants, so it
 *                     is now a serial dump from Settings.
 *   v3.0a 2026-09-08  Banner moved out of setup() into a first-connection
 *                     announce in loop(): USB CDC enumerates after setup()
 *                     begins, so the boot banner was being discarded and the
 *                     board looked dead over serial when it was running fine.
 *   v3.0  2026-09-08  Split into modules; display/touch/text extracted into
 *                     the reusable JCR_TouchScreen library. Behaviour is
 *                     v2.1's; the touch event queue moved from the RP2040
 *                     hardware FIFO to the library's own ring buffer, which
 *                     frees the hardware FIFO for application use.
 *   v2.1  2026-09-08  Darker palette; V/T chips fixed (toggling repaints the
 *                     plot so a hidden trace disappears; on/off states made
 *                     visually distinct).
 *   v2.0  2026-09-08  Rebuild on the dual-core touch architecture proven in
 *                     FABLE_DEV_TEST_SCREEN v1.1; raw 40 MHz ST7796 driver,
 *                     Russo One typography, per-button enlarged hit rects.
 *
 * Serial 115200. Every line that is not a CSV data row starts with '#'.
 * Keys:
 *   r  reset touch diagnostic counters
 *   d  toggle the once-per-second [tp] telemetry line
 *   t  re-initialise the touch controller (runs on core 1)
 *   L  toggle synthetic core-0 load (full-screen fill every loop)
 *   f  filter 0 <-> 20 samples
 *   e  ESC output arm (type-correct idle, 2 s hold) / cut
 *   p  print the ESC output state (set point, pulse on the pin)
 *   s  USB CSV stream on/off (not saved - use the LOG screen's SAVE)
 *   g  SD log start/stop
 *   m  remount the SD card
 * ========================================================================*/
#include <JCR_TouchScreen.h>

#include "Config.h"
#include "Theme.h"
#include "Layout.h"
#include "Format.h"
#include "Sampler.h"
#include "Widgets.h"
#include "Screens.h"
#include "Settings.h"
#include "EscOut.h"
#include "Logger.h"
#include "Version.h"
#include "Clock.h"

JCR_ST7796 tft(PIN_LCD_CS, PIN_LCD_RS, PIN_LCD_RST, PIN_LCD_LED, LCD_IPS != 0);
JCR_FT6336 touch(Wire1, PIN_CTP_SDA, PIN_CTP_SCL, PIN_CTP_RST, PIN_CTP_INT);
JCR_Text   gfxText(tft);

/* Core 0 sets this last, once the display is up; core 1 waits on it so the
 * two cores never race to initialise their buses. */
static volatile bool gCoreReady = false;
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
void loop() {
  /* Rolling average of one loop iteration, for Dev Mode's UI-rate readout.
   * Two micros() calls and a subtract — cheaper to always run than to gate. */
  static uint32_t lastLoopUs = 0;
  uint32_t nowUs = micros();
  if (lastLoopUs) {
    uint32_t dtUs = nowUs - lastLoopUs;
    gLoopUsAvg = gLoopUsAvg
        ? (uint32_t)(gLoopUsAvg + ((int32_t)dtUs - (int32_t)gLoopUsAvg) / 16)
        : dtUs;
    if (dtUs > gLoopUsMax) gLoopUsMax = dtUs;
  }
  lastLoopUs = nowUs;

  /* Announce on first serial connection, not from setup(). USB CDC only
   * enumerates after setup() has already started, so a banner printed there
   * goes to a port the host has not opened yet and is lost — which reads as
   * "the firmware isn't running" when it is. Announcing here also means
   * opening the monitor at any time reports which build is on the board,
   * without needing a reset. */
  static bool announced = false;
  if (!announced && Serial) {
    announced = true;
    /* Everything in this project's history so far was written on one day, so
     * a date alone does not identify a build. The compiler's own timestamp
     * does, and costs nothing. */
    Serial.println(F("# Logging Current Meter UI  " FW_VERSION));
    Serial.println(F("# built " __DATE__ " " __TIME__));
    Serial.println(F("# keys: r stats | d telemetry | t touch reinit | L load | f filter | e esc arm | p esc | s stream | g log | m mount | c clock"));
    Serial.printf("# touch: chip 0x%02X fw 0x%02X vendor 0x%02X %s\n",
                  touch.chipId(), touch.firmwareId(), touch.vendorId(),
                  touch.ok() ? "ok" : "INIT FAILED");
    Serial.printf("# settings: %s  theme=%u  filter=%u samples (%ums)\n",
                  settingsLoadedFromFlash() ? "loaded from flash" : "defaults",
                  (unsigned)gSet.theme,
                  (unsigned)FILTER_SAMPLES[gSet.filterIndex],
                  (unsigned)filterWindowMs(gSet.filterIndex));
    Serial.printf("# log: %s  mode=%u rate=%s threshold=%uA duration=%umin  stream=%s\n",
                  logCardText(), (unsigned)gSet.logMode, LOG_RATE_LABEL[gSet.logRateIdx],
                  (unsigned)gSet.logThreshA, (unsigned)LOG_DUR_MIN[gSet.logDurIdx],
                  streamOn() ? "on" : "off");
    checkTargetOverlaps();
    if (streamOn()) streamPrintHeader();
  }

  pumpTouchEvents();      /* never skipped, however slow the frame */
  serviceHeldTarget();    /* slider drag, hold-to-repeat                   */
  uint8_t escEv = escTick();  /* motion engine: ramps, cycles, Log Test    */
  escBarTick();           /* the armed strip, on whichever screen is up    */
  logTick();              /* drain samples: trigger, SD, USB stream        */
  if (escEv & ESC_EV_TEST_DONE) {
    /* Log Test finished its post-roll. The output is left live at neutral
     * unless it was cut mid-run, with EscOut's fuse running. Closed
     * after logTick() so the post-roll's last samples are in the file. */
    if (logTestActive()) logStop(escTestAborted() ? "aborted" : "complete");
    if (gScreen == SCR_TEST_LOG || gScreen == SCR_TEST_CYCLE || gScreen == SCR_TEST_MANUAL)
      showToast(escTestAborted() ? "Log Test aborted - log saved" : "Log Test complete - log saved");
  }
  logBarTick();           /* the recording strip along the bottom edge     */
  tickScreen(gScreen);
  updateToast();

  /* Synthetic load: ~60 ms of real SPI traffic per loop — the same pixel
   * count as a full-screen fill, which is worse than any frame the real UI
   * produces — but painted over the 4 px top strip sixty times so the screen
   * stays usable. If the fade reproduces faster with this on, it is core-0
   * sensitivity; if not, core-0 load is ruled out. */
  if (sLoad) {
    for (uint8_t i = 0; i < 60; i++) tft.fillRect(0, 0, tft.width(), ESC_BAR_H + 1, COL_GRID);
    escBarPaint();
  }

  telemetryTick();
  clockSaveTick();
  serialKeys();
}

/* ---- keeping the clock across power cycles ----------------------------
 * There is no RTC, so the only way the date survives a power cycle is a copy
 * in flash. Every 5 minutes the current time is written into the settings
 * blob — the clock fields only, never unsaved screen edits.
 *
 * An EEPROM commit stalls BOTH cores for a few milliseconds. That must never
 * land inside a capture (a hole in the data) or while the ESC output is live
 * (core 1 services the touch controller, so for those milliseconds the STOP
 * button does not answer, with a motor spinning). This is the one place that
 * knows about both, so every clock save in the firmware comes through here:
 * screen APPLY, the serial command, and the logger all call clockSaveSoon(),
 * which writes now if it is safe and otherwise leaves a request for the next
 * idle pass. A failed write leaves the request standing too. */
#define CLOCK_SAVE_MS (5UL * 60UL * 1000UL)

bool clockSaveBlocked() {
  return logRecording() || escArmed() || escTesting() || escCycling();
}

bool clockSaveSoon() {
  if (!clockUsable()) return false;
  if (clockSaveBlocked()) { clockSaveRequest(); return false; }
  if (settingsSaveClock()) { clockSaveDone(); return true; }
  clockSaveRequest();                 /* write failed - try again later    */
  return false;
}

static void clockSaveTick() {
  static uint32_t lastMs = 0;
  uint32_t now = millis();
  bool due = (now - lastMs >= CLOCK_SAVE_MS);
  if (!due && !clockSavePending()) return;
  if (!clockUsable()) { clockSaveDone(); return; }
  if (clockSaveBlocked()) return;     /* checked again next pass           */
  lastMs = now;
  if (settingsSaveClock()) clockSaveDone();
}

/* ---- once-per-second telemetry --------------------------------------- */
static void telemetryTick() {
  static uint32_t lastMs = 0;
  uint32_t now = millis();
  if (now - lastMs < 1000) return;
  lastMs = now;

  JCRTouchStats s;  touch.getStats(s);
  gLatUsAvg = sLatN ? (sLatSum / sLatN) : 0;

  /* availableForWrite() guard: a monitor that is attached but not draining
   * must never be able to stall core 0 — that would itself look exactly like
   * the fault being chased. */
  if (sTelemetry && Serial && Serial.availableForWrite() > 160) {
    uint32_t uiHz = gLoopUsAvg ? (1000000UL / gLoopUsAvg) : 0;
    Serial.printf("# [tp] t=%lus TP=%lu UI=%lu fmax=%lums lat=%lu/%lums dn=%lu up=%lu ovf=%lu "
                  "i2c=%lu drp=%lu jmp=%lu rng=%lu drift=%lu[%lu/%lu/%lu/%lu] svc=%luus "
                  "tick=%lu/%luus reinit=%lu esc=%u heap=%luk\n",
                  (unsigned long)(now / 1000), (unsigned long)s.sampleHz, (unsigned long)uiHz,
                  (unsigned long)(gLoopUsMax / 1000),
                  (unsigned long)(gLatUsAvg / 1000), (unsigned long)(gLatUsMax / 1000),
                  (unsigned long)s.downs, (unsigned long)s.ups, (unsigned long)s.overflows,
                  (unsigned long)s.i2cErrors, (unsigned long)s.dropouts,
                  (unsigned long)s.jumpGlitches, (unsigned long)s.rangeGlitches,
                  (unsigned long)s.regDrift,
                  (unsigned long)s.driftByReg[0], (unsigned long)s.driftByReg[1],
                  (unsigned long)s.driftByReg[2], (unsigned long)s.driftByReg[3],
                  (unsigned long)s.serviceUsMax,
                  (unsigned long)gTickOverruns, (unsigned long)gTickUsMax,
                  (unsigned long)s.reinits, (unsigned)escArmed(),
                  (unsigned long)(rp2040.getFreeHeap() / 1024));
  }

  /* Per-window maxima reset AFTER the line so Dev Mode and serial agree. */
  gLoopUsMax = 0; gLatUsMax = 0; sLatSum = 0; sLatN = 0;
  touch.resetServiceMax();
  gTickMaxResetReq = true;
}

/* ---- the clock command ------------------------------------------------
 * Every other bench key acts on the keystroke, with no Enter needed. 'c'
 * takes an argument, so it is the one that reads a line: after the 'c' the
 * characters are collected until a newline, or for 2 s if the sender does not
 * send one (the IDE's monitor can be set to "No line ending"), and then
 * parsed. Collecting is non-blocking — loop() keeps running through it.
 *
 *   c                     print the time and how much to trust it
 *   c 1790084323          local epoch seconds — what a script sends
 *   c 2026-09-23 14:05:30 the same thing, typed by hand (seconds optional)
 *
 * The 2 s is an idle gap between characters, not a deadline for the whole
 * command: typing a date by hand in a raw terminal takes longer than that.
 * ---------------------------------------------------------------------- */
static char     sClkLine[40];
static uint8_t  sClkLen        = 0;
static bool     sClkCollecting = false;
static uint32_t sClkStartMs    = 0;
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

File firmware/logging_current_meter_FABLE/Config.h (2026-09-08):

/* ==========================================================================
 * Config.h — everything you would change to move this firmware to different
 * hardware: pin map, bus rates, sampling cadence, calibration constants.
 *
 * Calibration values are produced by display_bringup.ino's serial v/i/n
 * routines; paste fresh numbers here and reflash. The Calibrate screen shows
 * them read-only along with whether each has actually been fitted.
 * ========================================================================*/
#pragma once
#include <Arduino.h>

/* ---- pin map (Waveshare RP2040-Zero + 3.5" ST7796/FT6336U on one FPC) ---- */
#define PIN_SCK       2
#define PIN_MOSI      3
#define PIN_MISO      4
#define PIN_LCD_CS    5
#define PIN_LCD_RS    6      /* DC: data/command select                    */
#define PIN_LCD_RST   7
#define PIN_LCD_LED   8      /* solid HIGH only — never PWM (see below)    */
#define PIN_SD_CS     9      /* park HIGH: shares the FPC's MISO           */
#define PIN_CTP_SDA  10
#define PIN_CTP_SCL  11
#define PIN_CTP_RST  12
#define PIN_CTP_INT  13
#define PIN_I_SENSE  26      /* ADC0 — ACS770 current sensor               */
#define PIN_V_PACK   27      /* ADC1 — pack voltage divider                */
#define PIN_T_SENSE  28      /* ADC2 — NTC thermistor divider              */
#define PIN_V5_SENSE 29      /* ADC3 — +5V rail / 2, ratiometric reference */
#define PIN_ESC_SIG   1      /* ESC servo signal out — hardware PWM slice   */

/* ---- display / touch ---- */
#define LCD_ROTATION   1            /* 1 = 480x320 landscape               */
#define LCD_IPS        1            /* IPS panel: needs INVON or every colour
                                     * displays as its complement. The lcdwiki
                                     * MSP3526 / Hosyond 3.5" is IPS.         */
#define SPI_HZ         40000000UL
#define TOUCH_I2C_HZ   400000
#define TOUCH_HZ       200          /* touch samples per second on core 1  */
#define TOUCH_NATIVE_W 320          /* the touch panel's own portrait size */
#define TOUCH_NATIVE_H 480
#define TOUCH_INVERT_X false        /* flip if the crosshair mirrors your  */
#define TOUCH_INVERT_Y false        /* finger — crosshair is ground truth  */

/* ---- sampling ---- */
#define ADC_MAX          4095.0f
#define G2_OVER_G1      0.755319f   /* cancels VCC/VREF in the current ratio */
#define ADC_AVG               64    /* oversample count (RP2040 ADC DNL)     */
#define TICK_US            13158UL  /* 5 s / 380 graph columns               */

/* ---- calibration (paste from display_bringup's v/i/n routines) ---- */
#define V_GAIN_CAL       0.01662778f   /* volts per ADC count             */
#define V_OFFSET_CAL    -0.13632f      /* volts                           */
#define V_CAL_VALID      1
#define I_QUIESCENT_CAL  0.105399f     /* ratio at 0 A — MEASURED         */
#define I_ZERO_VALID     1
#define I_SENS_CAL       0.00533200f   /* ratio per amp — NOMINAL         */
#define I_GAIN_VALID     0
#define RV1_OHMS       100830.0f
#define NTC_B            3836.6f
#define NTC_R25         97988.0f

/* ---- UI frame gates ---- */
#define LIVE_FRAME_MS   50
#define GRAPH_FRAME_MS  33
#define DEV_FRAME_MS    50
#define TOAST_MS        1600

/* Two hardware rules that are not negotiable:
 *  - PIN_SD_CS must be driven HIGH before anything else touches the SPI bus.
 *    It shares the FPC's MISO; floating low, the card fights the display.
 *  - PIN_LCD_LED is a solid level, never analogWrite(). V5_SENSE only passes
 *    to ~318 Hz, so PWM at ~1 kHz injects current noise no calibration
 *    removes (DESIGN.md section 4.2). */

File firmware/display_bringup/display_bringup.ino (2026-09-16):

/* ============================================================================
 * RC Logging Current Meter - Rev A board bring-up diagnostic
 * ----------------------------------------------------------------------------
 *   VERSION 2.1          LAST UPDATED 2026-09-05 12:40 EDT
 *
 *   The banner printed at boot repeats this stamp AND the compiler's own build
 *   time, so you can confirm from the serial log that the board is running the
 *   file you think it is.  If FW_UPDATED below does not match what you expect,
 *   you have the wrong copy; if the BUILT time is stale, the IDE did not
 *   recompile.
 *
 *   2.1  2026-09-05  Thermistor refined: B=3836.6 from the run with BOTH
 *                    ends verified, R25=97988 still anchored on the dry
 *                    FNIRSI point. Taking each parameter from the run that
 *                    measured it best removes a systematic ~0.7 C warm bias.
 *   2.0  2026-09-05  Thermistor FITTED: B=3893.8, R25=97804, from 22.1 C
 *                    and 99.0 C. The ice bath was abandoned - three tries
 *                    all produced resistances implying ~16 C, and 77 C of
 *                    spread settles B just as well. All four analog
 *                    channels now have measured constants.
 *   1.9  2026-09-05  NTC fit now rejects physically implausible results
 *                    (+/-15% on B, +/-25% on R25) instead of printing them
 *                    as if they were usable, and says what to check. A fit
 *                    returning R25=57k for a part the DMM reads at 111k
 *                    at 22 C is bad DATA, not a bad part. Also warns to
 *                    seal the probe - bare leads in water shunt the
 *                    thermistor and break the cold point specifically.
 *   1.8  2026-08-25  FIXED: v1.7 baked the NOMINAL quiescent 0.1 rather than
 *                    this board's measured 0.105399, so the board read a
 *                    phantom 1.01 A with nothing connected. Current zero and
 *                    gain are now tracked separately, because the zero is
 *                    calibrated and the gain is not - reporting both as one
 *                    flag was hiding which number to trust.
 *   1.7  2026-08-25  Calibration constants BAKED IN rather than living in
 *                    RAM: V_GAIN_CAL / V_OFFSET_CAL from the 9.99 V and
 *                    57.03 V fit now survive a reflash. New 'c' command and
 *                    a boot line show what is stored and which channels are
 *                    genuinely calibrated. Current still nominal - waiting
 *                    on the numbers from 'i'.
 *   1.6  2026-08-25  V_PACK check reworded - it is a safety interlock, and
 *                    reporting FAIL during a deliberate voltage calibration
 *                    read like a board fault.
 *   1.5  2026-08-25  Backlight is now driven SOLID HIGH, never PWM'd, and
 *                    SW1 no longer dims it. PWM at ~1 kHz sits in the gap
 *                    between I_SENSE's 10 kHz and V5_SENSE's 318 Hz, where
 *                    the 4.2 ratiometric correction cannot cancel it - it
 *                    was injecting uncorrectable current noise.
 *   1.4  2026-08-25  Graph sampling moved to CORE 1 (DESIGN.md section 11's
 *                    own split). v1.3 managed only ~25 Hz because a 31 ms
 *                    draw blocked the sampler and missed samples were
 *                    dropped, so 388 columns spanned ~15 s on an axis
 *                    labelled 5 s. Interval is now microseconds with
 *                    catch-up, and the ACHIEVED rate is measured and shown
 *                    on the panel rather than assumed.
 *   1.3  2026-08-25  Live V/I graph, command 'g': 5 s scrolling window,
 *                    volts blue on the left axis, amps red on the right,
 *                    2 px traces, autoscaling. Touch inverts reverted to 0
 *                    (the crosshair under the finger is the ground truth,
 *                    not a verbal description). Crosshair enlarged to a
 *                    ring plus long arms, and 'x' now clears the screen so
 *                    erasing with black stops punching holes in the test
 *                    pattern.
 *   1.2  2026-08-25  MISO test downgraded from FAIL to INFO when it reads
 *                    0xFF. With no SD card in the slot nothing drives that
 *                    pin on these modules, so 0xFF is the expected result
 *                    on a healthy board with a working panel. S11 can only
 *                    be answered with a card inserted.
 *   1.1  2026-08-25  Touch responsiveness. Root cause was FT6336U register
 *                    0x86 - monitor mode is ALLOWED by default and 0x87
 *                    drops into it after 30 s idle. Now forbidden, scan
 *                    period set fastest, I2C raised to 400 kHz, and CTP_INT
 *                    (GP13) drives an ISR flag so reads are event-driven
 *                    with a 50 ms timed fallback. Reports how each sample
 *                    was triggered so a dead CTP_INT is visible.
 *   1.0  2026-08-25  Touch mapping SOLVED on hardware: TOUCH_INVERT_X and
 *                    TOUCH_INVERT_Y both 1 at LCD_ROTATION 1. Display,
 *                    touch, all four ADC channels and the thermistor are
 *                    now all working. Buttons remain dead (footprint bug).
 *   0.9  2026-08-25  FIXED: the Enter that starts a command was being read
 *                    as a second keypress one iteration later. That killed
 *                    the 'x' and 'A' streams instantly, and made 'n'/'v'/'i'
 *                    abort on an empty prompt. CR/LF is now ignored as a
 *                    keypress and drained after each command. 'x' also runs
 *                    the touch scan itself if it has not run yet.
 *   0.8  2026-08-25  Pack-voltage calibration ('v', two-point linear with
 *                    offset) and current calibration ('i', tare then gain,
 *                    plus an optional check point). Both applied live for
 *                    the session; adcReport marks readings CALIBRATED or
 *                    nominal.
 *   0.7  2026-08-25  Two-point NTC calibration added, command 'n'. Solves
 *                    R25 and B from an ice bath and boiling water, and
 *                    prints the #defines to paste back in.
 *   0.6  2026-08-25  RV1_OHMS refined to 100.83k on an FNIRSI 2C53T.
 *                    NTC confirmed ~2.4% below nominal R25 across two
 *                    room temperatures - a real part offset, not noise.
 *                    Left NTC_R25 nominal pending an ice-bath fit.
 *   0.5  2026-08-25  RV1_OHMS set to the measured 100.7k (was a nominal
 *                    100k). Thermistor now agrees with a reference meter to
 *                    +0.43 C at room temperature.
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

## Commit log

2026-08-24 Initial commit: Logging Current Meter KiCad project
    RC current/voltage logging meter based on ACS770 hall sensor and RP2040-Zero.
    Includes:
    - KiCad 8 schematic, PCB, and project files
    - LCM.pretty / EasyEDA.pretty / Samacsys.pretty custom footprints
    - LCM.kicad_sym and vendor symbol libraries
    - generator/ Python scripts for schematic, PCB, BOM, and library generation
    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
    [BOM.csv, Logging_Current_Meter.kicad_pcb, Logging_Current_Meter.kicad_sch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]
2026-08-24 Add licences: CC BY-NC-SA 4.0 for hardware, PolyForm Noncommercial 1.0.0 for generator/
    Hardware design (schematic, PCB, footprints, symbols, BOM, docs) is CC BY-NC-SA 4.0.
    generator/ Python is PolyForm Noncommercial 1.0.0 -- CC advises against CC licences
    for software, so code gets a licence written for code.
    Both restrict commercial use, so this is source-available rather than open source in
    the OSI/OSHWA sense. Personal builds and modifications are permitted with attribution
    and share-alike; commercial sale requires separate permission.
2026-08-24 Correct KiCad version claims: files are KiCad 10, not KiCad 8
    The schematic and board were bumped to KiCad 10 format when KiCad 10 opened and saved
    them (20260306 and 20260206, both stamped generator_version 10.0). DESIGN.md 12 still
    described the original KiCad 8 generator output as the current format, and the README
    repeated it. KiCad 10 or newer is now required to open the project.
    Also resolves the two format assumptions in DESIGN.md 14. KiCad 10 accepted and rewrote
    the board, which is the KiCad-written example that was missing: four copper layers in the
    stackup, and no top-level (nets ...) index, so zone and via nets by name was correct.
    Flags gen_sch.py as a historical build script.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
2026-08-25 Add display bringup firmware, sensor supply notes, and ignore local-only files
    firmware/display_bringup is a hardware diagnostic that proves the FPC ribbon, ST7796U
    panel, FT6336U touch, backlight and buttons over USB serial before any real firmware is
    written. Each stage reports OK or FAIL naming the net and FPC pin, so a dead conductor
    identifies itself. USB power only, nothing in the 60 V path.
    DESIGN.md gains 4.1.2 on sensor supply and decoupling: why C3 is not supply decoupling,
    and why R5 taps +5VS rather than +5V.
    Gitignores .history/ (VS Code Local History scratch, contains an empty nested .git) and
    LCM_Purchased_BOM.xlsx (carries Amazon and JLCPCB order numbers plus affiliate link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
    [display_bringup.ino]
2026-08-25 Separate the three cost figures in the README
    BOM.md's $10.75, the README's ~$15 and the complete-unit cost were being read as
    competing claims about the same number. They measure different things: theoretical SMT
    parts at LCSC prices, a delivered assembled board at qty 10, and a complete meter
    including the display. State all three and what each covers.
    Actual JLCPCB PCBA came in at $11.06/board against BOM.md's $10.75 theoretical, which
    validates the generated BOM. Figures are all at qty 10.
2026-09-05 Sync Rev A bring-up state, calibration, and add the touchscreen UI sketch
2026-09-05 logging_current_meter_ui: v1.7 - fix Dev Mode overlap, touch-hold debounce
    [logging_current_meter_ui.ino]
2026-09-08 gitignore: exclude the Claude outputs working folder
    It stages duplicate copies of files that also live in firmware/ and libraries/,
    alongside artefacts from unrelated tasks. The canonical copies are the ones in
    the tree.
2026-09-08 firmware: extract JCR_TouchScreen library and rebuild the UI as modules
    The display, dual-core FT6336U touch engine and text renderer were ~950 lines of
    general-purpose code buried in the meter sketch, and are now an installable
    Arduino library with three examples, while the UI itself is split from one
    2,360-line file into 21 modules that use it. Touch is fixed at the root rather
    than patched: the controller runs in polling mode, sampled at a fixed 200 Hz on
    core 1 between ADC channel bursts, so a slow frame delays the reaction to a tap
    but never its registration. A line-by-line review against v2.1 found no
    divergence in ADC maths, layout or dispatch, and caught four real defects, all
    fixed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
    [Config.h, Layout.h]
2026-09-08 JCR_TouchScreen 1.1.0: fix IPS colour inversion, add controller watchdog and reinit
    The ST7796 init table sent INVOFF where the IPS panel needs INVON, so every colour since v2.0 displayed as its complement; the constructor now takes an ips flag, default on. The FT6336U driver gains a register watchdog that reads its four configuration registers back every 500 ms, counts and rewrites any that drifted, plus per-sample transaction timing and a cross-core reinit request. On hardware the watchdog found the mode register drifting 47 times in 39 minutes, which is the current lead on touch fading with use. All three examples compile clean; details in COMMIT_TIMELINE.md.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
2026-09-08 firmware: v3.1c - Test Mode, Settings, themes, V/I filter, touch harness
    Adds ESC signal generation on GP1 (hardware PWM, manual set point and timed auto-cycle, off at boot and only ever persisted at idle), a Settings screen with explicit-save flash persistence, runtime dark and navy themes, and a weighted moving average on the V and I readings that leaves peaks raw. The Calibrate screen is gone in favour of a serial dump, the Russo fonts were regenerated to include the '+' and '/' they had been missing, and every screen carries a serial telemetry harness for the touch-fade investigation. Compiles clean at 102,828 bytes flash; bench-tested through v3.1b, with v3.1c's remaining changes compil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
    [Config.h, EscOut.cpp, EscOut.h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]
2026-09-16 firmware: v3.2 - fix ESC pulse timing, add SD logging and USB stream
    arduino-pico silently clamps analogWriteFreq() to 100 Hz, so v3.1's 50 Hz ESC frame ran every pulse at half width; GP1 now drives its PWM slice through the Pico SDK at 1 us per count and always arms at idle with a 2 s hold. New LOG screen logs raw and filtered V/I, temperature, ESC pulse and energy since start to SD, started manually, by Test Mode's cycle, or by a current threshold with a 1-15 min duration. The same rows minus energy stream over USB, all other serial output is now '#'-prefixed, and tools/capture_stream.py records the stream on a PC. Compile-checked on arduino-pico 6.1.0 and host-simulated, not yet bench-ver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
    [EscOut.cpp, EscOut.h, Layout.h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]
2026-09-17 firmware: v3.2a - log file names, clearer LOG steppers, log analyzer
    Log files are now named LOG_<n>_<MODE>_<V>V.CSV, where n counts up from the highest number on the card and V is the pack voltage at the start. LOG MODE uses wrapping arrow buttons, RATE's + now means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
2026-09-23 JCR_TouchScreen 1.2.0: add lastGoodSampleMicros() for fail-safe held controls
    The FT6336 service loop returns early on I2C errors and impossible readings without republishing state or queuing a release, so isDown() can stay true with a frozen point. lastGoodSampleMicros() stamps every successful publish, letting a consumer treat stale data as a release. Firmware v3.3's dead-man slider uses it. No behaviour change for existing callers.
2026-09-23 firmware: v3.3 - Test Mode rework: manual, ramped cycle, logged cycle test
    Test Mode is now three tabs (Manual, Cycle, Log Test) under one header with a STOP that cuts the ESC output from anywhere, and supports one-direction (1000 us) or bidirectional (1500 us neutral) ESCs, chosen with an arrow-icon toggle. Manual control offers +/- buttons with hold-to-repeat (coarse steps in lime) or a tap/drag slider with a dead-man option; cycles use a saved profile with linear ramps and dwells edited via tiles. Log Test records LOG_n_TEST files with a 3 s pre-roll, N cycles, 5 s post-roll and auto-disarm, and the log analyzer shows the profile and an ESC pulse strip. Compile-checked and host-tested, no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
    [EscOut.cpp, EscOut.h, EscProfile.h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]
2026-09-23 firmware: v3.4 - settable wall clock, stamped into every log
    The board has no RTC, so this adds a software clock: an epoch base plus millis(), set from a new SET CLOCK screen (Settings -> CLOCK) or over serial with the new 'c' command, which takes either epoch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

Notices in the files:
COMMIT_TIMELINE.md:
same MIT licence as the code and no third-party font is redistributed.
